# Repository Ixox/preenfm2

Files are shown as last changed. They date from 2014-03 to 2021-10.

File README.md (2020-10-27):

# preenfm2 firmware

Ixox/preenfm2 is the official repository of the preenfm2 firmware.

You can find here the compiled firmware, its code source and some hardware files for the PCB, MCU board and cases.

To flash the preenfm2 for the first time, [follow these instructions](https://github.com/Ixox/preenfm2/tree/master/flash)

## Compiling the firmware

To compile the firmware, you'll need [arm-gcc version 4.7](https://launchpad.net/gcc-arm-embedded/+milestone/4.7-2014-q2-update)

Add the bin directory to your PATH, and run **'make'**, you'll get the list of the available targets.

```bash
$ make
You must chose a target 
Don't forget to clean between different build targets
   clean : clean build directory
   pfm : build pfm2 firmware
   pfmcv : build pfm2 firmware for Eurorack 
   installdfu : flash last compiled firmware through DFU
   zip : create zip with all inside
```
Since some refactoring, the bootloader does not compile anymore. But it's available in its binary format.

Then put your preenfm2 in [bootloader mode](http://ixox.fr/preenfm2/manual/upgrade-firmware/). Look at DFU part 4.

To flash the firmware on the preenfm2 using the DFU protocol :

```bash
make installdfu
```

Once it's done, unplug the power cable and plug it back.

## New Filters in 2.11

Many effects have been added in the firmware 2.11. They were coded by [Toltekradiation](http://ixox.fr/forum/index.php?topic=69544.0).

His github repo is [here](https://github.com/pvig/preenfm2). You'll find there some description of the different effects.

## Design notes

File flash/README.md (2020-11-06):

You may need to flash the memory of the preenfm if it was not done before.

The following need to be done only once. Once the bootloader is flashed, you may boot into it (hold a key while turning on the preenfm2) and flash the firmwares from it.

More information about the preenfm2 bootloader is accessible [here](http://ixox.fr/forum/index.php?topic=69716.0).

# Flash the STM32F405 on Windows

## WebDfu

Flashing the firmware is now possible from a Chrome browser:  
https://devanlai.github.io/webdfu/dfu-util/

If it works this is probabely the easier way.

Reminder to enter DFU mode :
1. Unplug the preenfm
2. Connect the 2 pins of the Boot0 pins of your preenfm2
3. Plug the preenfm

When your preenfm2 is in DFU mode and plugged to your compuer throught USB.

* Click Connect button : select "STM32 Bootloader"
* Then select the first interface of the list "DFU: cfg=1, intf=0, alt=0, name="@Internal Flash /0x08000000/04*016Kg,01*064Kg,07*128Kg"
* Keep default values and go to "Firmware Download". Click "Choose file" and select your "p2_boot_1.13.bin" from your computer.
* Verify your screen with the attached screenshot.
* Click Download

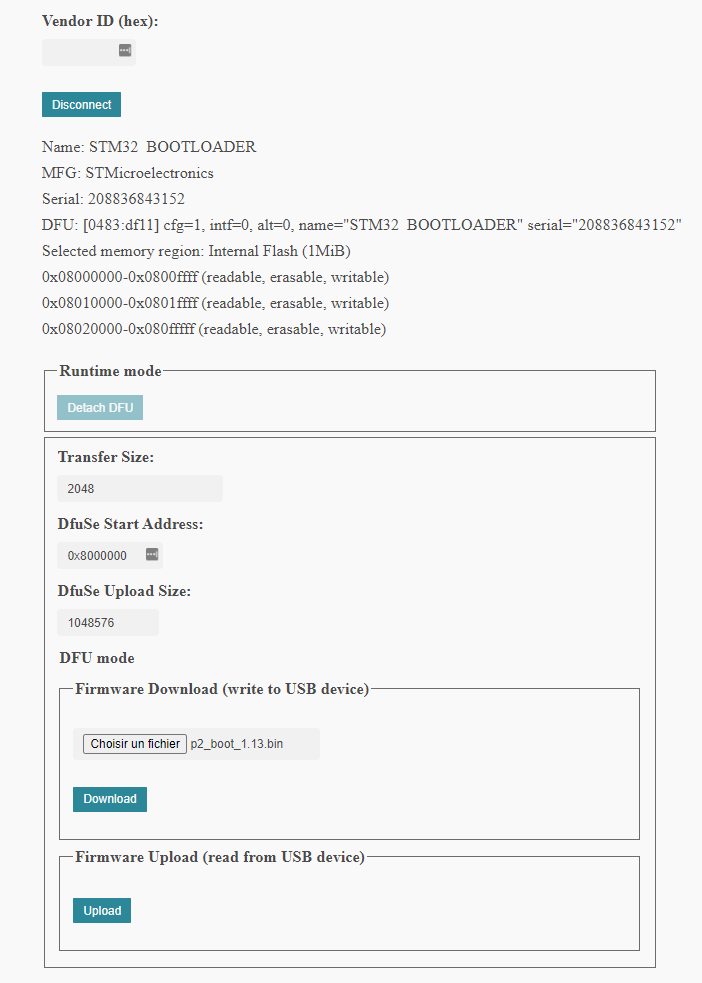
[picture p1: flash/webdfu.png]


Once finished reboot while holding down a key.
You should see "- Bootloader 1.13 -" at the top of the preenfm2 screen.

## DfuSe

Another way is to download [DfuSe](https://www.st.com/en/development-tools/stsw-stm32080.html) from STMicroelectronics.   
It contains the flash programm and the usb required drivers.

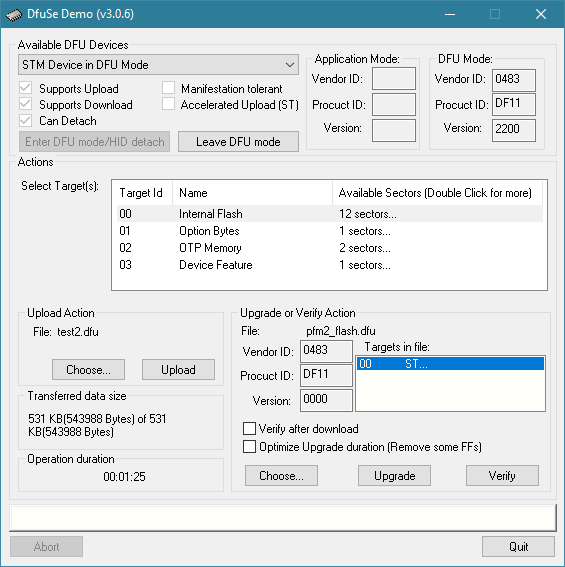
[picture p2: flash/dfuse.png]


Once your preenfm is in DFU mode it should show up in the top left as "STM DEvice in DFU Mode".
Then in the "Upgrade or Verify Action" click on Chose, select the [pfm2_flash.dfu](pfm2_flash.dfu) that should be in the current folder.
And click on Upgrade.

When it's done don't forget to unconnect the 2 pins of Boot0 before turning off and back on your preenfm.

## Windows 3rd solution

Use the commands as explained bellow

# Flash the STM32F405 on MacOs or Linux

On those platforms you'll have to use "dfu-util".

On linux create a new file  /etc/udev/rules.d/46-stm32F405.rules and add this content :
```
   ATTRS{idProduct}=="df11", ATTRS{idVendor}=="0483", MODE="664", GROUP="plugdev"
```

First follow steps 1,2,3 above to enter bootloader mode.

Then flash the bootloader at the adress 0×8000000. (run install_bootloader.cmd from the firmware zip file or from the current folder)

```
dfu-util -a0 -d 0×0483:0xdf11 -D p2_boot_1.11.bin -R -s 0×8000000
```

Flash the firmware at the adress 0×8040000.  (run install_firmware.cmd from the firmware zip file)

```
dfu-util -a0 -d 0×0483:0xdf11 -D pfm2_211.bin -R -s 0×8040000
```

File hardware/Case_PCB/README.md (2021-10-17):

# preenfm2 2021 case

I designed this new case to have a cheap good looking case for the preenfm2.  

The top surface is a PCB. The rest of the case is made by 2 3D printable pieces (main and rear surface).  
The hole for the display fits regular 20x4 **LCD** display such as [this one](https://www.buydisplay.com/arduino-code-lcd-20x4-i2c-character-display-module-wide-view-angle).  
So check the size. You can also modify the provided Kicad PCB file. 

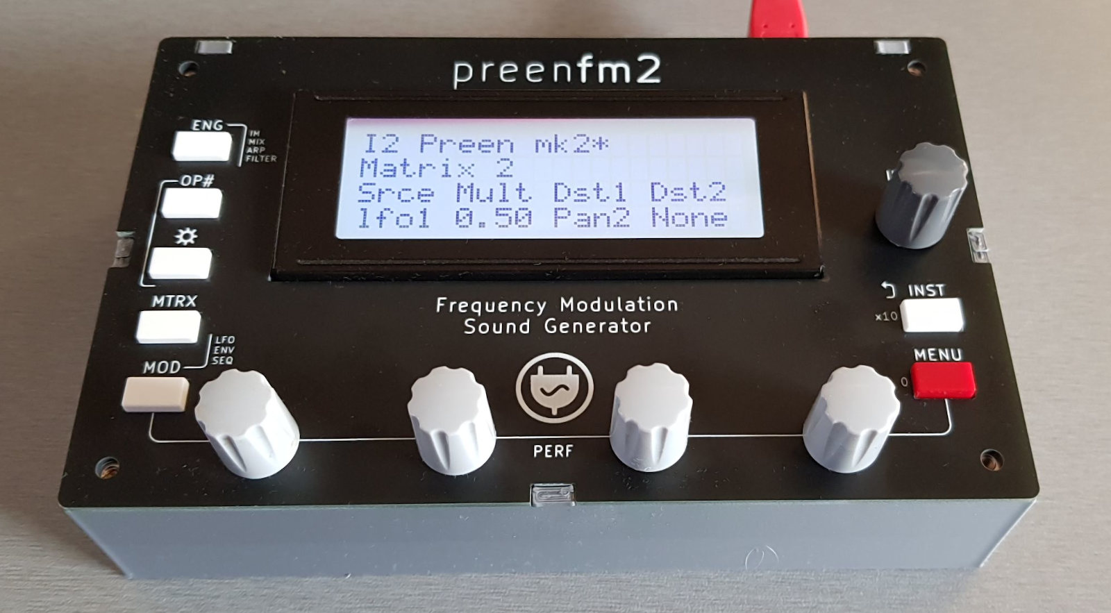
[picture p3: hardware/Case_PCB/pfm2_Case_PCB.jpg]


Other items: 
* 4 * 12 mm F/F spacers
* 2 * 20 mm M/F spacers
* 2 * 15 mm M/F spacers
* 8 * 8 mm screws
* 4 * self adhesive rubber feet (optional)

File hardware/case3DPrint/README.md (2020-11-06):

# 3D Printed Case

Here are 4 stl files that can be printed to make a minimal enclosure for your preenfm2.  
It will work with LCD display, OLED displays are smaller and the result won't be nice.  

The f3d file can be imported into fusion 360. Fusion 360 has a free version for personnal use. Using it you can customize the case and recreate the STM files.

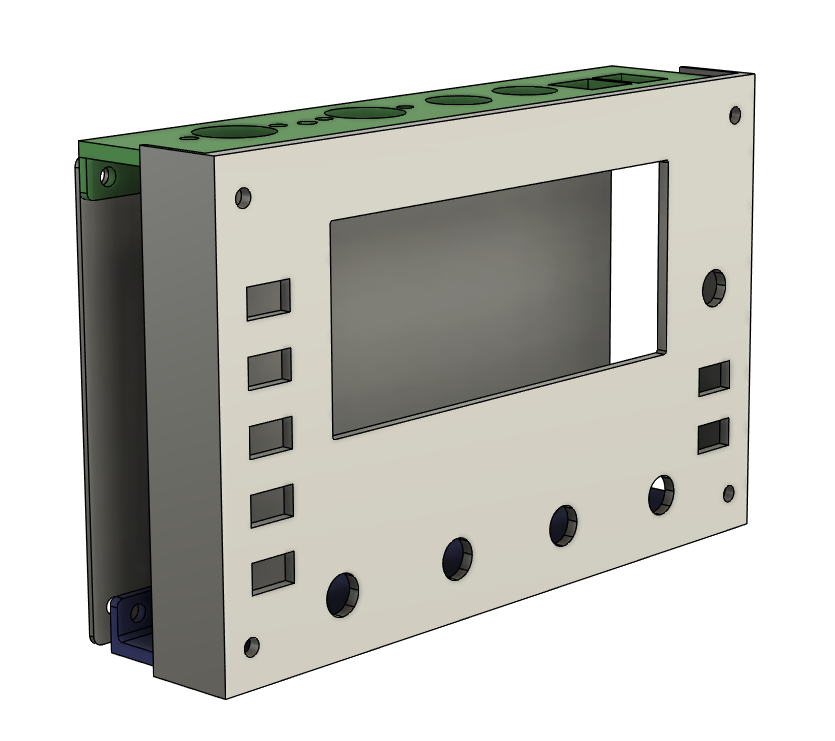
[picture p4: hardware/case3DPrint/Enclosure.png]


Additional hardware :
* 4 * 12 mm F/F spacers
* 2 * 20 mm M/F spacers
* 2 * 15 mm M/F spacers
* 8 * 8 mm screws
* 4 * self adhesive rubber feet (optional)  

Screws and spacers size can be M2.5 or M3.

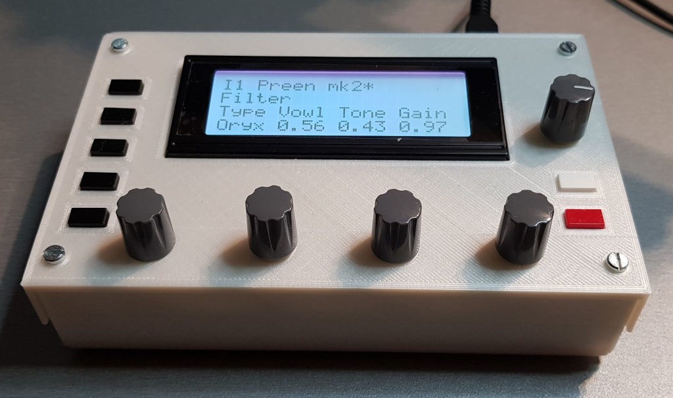
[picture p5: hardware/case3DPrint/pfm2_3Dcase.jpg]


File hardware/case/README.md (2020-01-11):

# Preenfm2 case files

Here are 2 svg files that can be used to have a case made at Formular/Ponoko or any laser cuting company.

Chose the correct file : OLED and LCD 20x4 display don't have the same bezel size.

* To fix the display to the PCB :
    * 2 \* M2.5 screws 16mm
    * 2 \* M2.5 nuts
    * 2 \* Spacer 8mm M3 (ref mouser 855-R30-6700894)
* To fix the 2 midi jacks to the case
    * 4 \* M2.5 screws 8mm
    * 4 \* M2.5 nuts
* To screw the case parts together
    * 9 \* M3 screws 6mm (5 bottom + 4 top)
    * 5 \* DI20 spacers (ref mouser 855-R30-1002002)
    * 4 \* DA11 spacers (ref mouser 855-R30-3001102)
    * 4 \* M3 nuts
    * 4 \* M3 screws 12mm
* Under the case
    * 2 \* stick on feet (ref mouser 517-SJ-5306CL)

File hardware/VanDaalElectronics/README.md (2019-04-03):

# Eurorack PCB eagle files for the preenfm2

Here is the first revision Eagle files for the Eurorack daughter board.
This board converts Modulation inputs (cv3 and CV4) -5V to +5V for Preen AIN
It handles V/Oct 0-8V from CV2 to AIN and Gate from CV1 to AIN.

All the unnamed diodes are general purpose diodes.
Shotky diodes are also what ever fits. As long it has very low forward voltage.

CV inputs can be wired straight to 3.5mm jacks.
Same with MIDI and USB.

+5V needs to be routed to the mainboard.

[Van Daal Electronics DIY Kit](https://vandaal-electronics.com/product/preenfm-eurorack-retrofit-diy-kit/)

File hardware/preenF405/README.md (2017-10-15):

'''html
### PreenF405

Here is the schematic and board of the preenFM microcontroller board.
Files have been created with eagle 6.5.

The BOM used for the official preenF405 is :
<pre>
Manufacturer       Part Number         Designator        Qty  Desciption                       Case            Top/bot Points
Yageo              CC0603KRX7R9BB104   C1, C2, C3, C4    4    100nF,50V,10%,X7R,0603           0603     SMD    Top     2    
Murata             GRM1885C1H200FA01D  C6, C7            2    20pF,50V,1%,C0G,0603             0603     SMD    Top     2    
TDK Corporation    C2012X7R1H225K125AC C8, C9            2    2.2uF,50V,10%,X7R,0805           0805     SMD    Top     2    
Kemet              T491B106K016AT      C10               1    10uF,16V,10%,1411(B)             1411(B)  SMD    Top     2    
Yageo              RC0603FR-0710KL     R1, R2, R3, R6    4    10K,1%,1/10W,0603                0603     SMD    Top     2    
Yageo              RC0603FR-0722RL     R4, R5            2    22R,1%,1/10W,0603                0603     SMD    Top     2    
TXC Corporation    AT-12.000MAGK-T     QA                1    12MHz,20pF,HC49/US               HC49/US  SMD    Top     2    
STMicroelectronics STM32F405RGT6       IC1               1    STM32F405RGT6,64-LQFP            64-LQFP  SMD    Top     64   
TAD                1-2001FBV0T                           2    1*20 Pins,Pitches 2.54mm,180°                    Bot     20   
</pre>

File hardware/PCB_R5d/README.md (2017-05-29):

# Preenfm2 PCB files

Here is the preenfm2 PCB files : revision r5d.<br />
Made with [Kicad](http://kicad-pcb.org/) 3.<br />

<br />
### What's new ?<br />
Compared to r5c, there is an additional resistor that makes [the yellow oled mod](http://ixox.fr/forum/index.php?topic=69159.0) much easier.<br />

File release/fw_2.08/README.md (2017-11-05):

### Do not right click !
Click on the firmware's file, then press Download on the following page.

# What's new in 2.08 ?

# Carrier vs Modulator
#### Direct editing : 
There's a new combo button+encoder: <br />
Modifying some value while pressing the left middle button (button 3 from this picture) will modify  other values at the same time.<br />
If you modify any of the 8 enveloppe parameters while pressing this button, it will modify the other enveloppes of the same operator type in the current algo : all carriers or all modulators. <br />
Exemple with <a href="http://ixox.fr/preenfm2/algorithms/algo15/#main">ALGO 15</a> <br /> 
If you press button 3 while modifying enveloppe of operator 1 (or 3) it will modify 1 & 3 at the  same time.<br />
If you press button 3 while modifying enveloppe of operator 2 (or 4 or 5 or 6) it will modify 2,4,5 & 6 at the same time.<br />
An other example :  Modifying attk of op1 (which is always a carrier operator) while pressing 3 will always modify the attk of the sound because all carriers attk will be modified :)<br />
It also does the following multi-edit :<br />
IM : modifying any modulation index (or v) will edit all IM (or all v) at the same time.<br />
Mix : modifying any mix will change all mix.<br />
Pan : modifying any pan will change all pans.<br />

#### Matric modulation :
The legacy att*, dec*, rel* matrix targets are now envC, decC, relC and modify attack, decay and release of all carrier operator envelopes.<br />
After each one you'll find envM, decM, relM that modify attack, decay and release of all modulator operator envelopes.<br />
Controlling all modulator envelopes with the modwheel (matric source ModW) is very intersting.<br />

#### Midi control:
. Legacy midi CC 80 now modifies enveloppe attacks of all carrier operators.<br />
. Legacy midi CC 81 now modifies enveloppe releases  of all carrier operators.<br />
. New midi CC 62 modifies enveloppe attacks of all modulator operators.<br />
. New midi CC 63 modifies enveloppe releases  of all modulator operators.<br />
Midi page updated : http://ixox.fr/preenfm2/manual/midi/<br />

# LFO Frequency
LFO1-3 frequency can now go up to 99.9Hz.<br />
!!! Your frequencies synced to midi clock (MC/16,  MC/8, MC/4 etc....) will be 24.x Hz after this modification.
Which means you'll have to turn their values up after 99.9 to set back your Midi clock synced values !!!!<br />

# Lokki's modification 
http://ixox.fr/forum/index.php?topic=69326.0<br />
1. hertz mode: in the Operator Oscillator page, chose Ftyp = kehz. That will make "fine tune" (FTun) value behaves in hertz. So that beating stays the same over the whole range of the midi notes.<br />
2. global midi channel: if enabled in the menu (MENU>Tools>Set>Global Ch),  midi coming in to this channel will be sent to all four instruments. <br />

# Step Sequencer and NRPN
NRPN used to always modify the step sequencer of the curren instrument, not the one of the specified midi channel. It's now fixed.

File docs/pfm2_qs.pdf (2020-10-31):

## http://www.preenfm.net

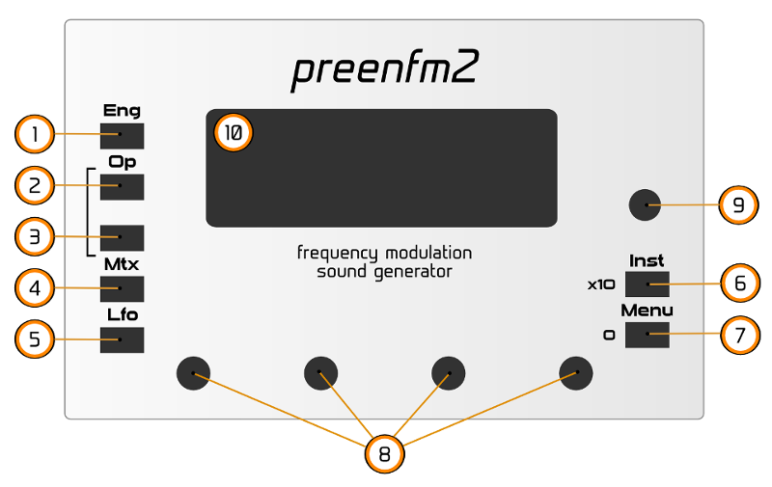
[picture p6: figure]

- Hold 1 + 7 : show current FM algo
- Hold 1 + 6 : show current IM
- Mix, pan, env edit : hold 3 to modify all other carrier/modulator operators at the same time
- Hold 1, 2, 4, 5, 6 and turn any encoder to navigate quickly through the pages
- Hold any key while powering the preenfm enter bootloader to flash new firmware.
- Hold 6 + encoder : modify value 10 times faster
- Hold 7 + encoder : reset value
- Hold 1 and press 2 : go to main engine page.
- Hold 6 + 1-5 : play note

1 – 5 : preset edition. Press same button again or (button + encoder) to navigate through the pages of each button.
6 : change curent instrument or ‘back’ in menu mode
7 : enter menu mode (in menu mode 6 become back button) 8 : change values
9 : analog volume

1 : engine, Modulation, Mixer, Arpegiator, Filter
2 : operator from 1 to 6
3 : for operator selected in 2 : waveform, enveloppe
4 : matrix row from 1 to 12
5 : LFO and modulators : lfo1-3, env1-2, step seq 1-2, midi note modulator 5 + 7 (or 8 if clickable) : performance

You enter menu after pressing 7
6 is the Back button. When at the top, returns to edit mode. . Load > Bank, Combo, DX7, Randomiser
. Save > Bank, Combo, Default combo
. Tools > settings, create, rename, Scala
Randomizer : encoder to modify what is changed, 1-5 button to trigger new random Settings: Enc 1 changes setting, Enc 2 changes value. Press 7 again to save.

## Edit Menu Tips

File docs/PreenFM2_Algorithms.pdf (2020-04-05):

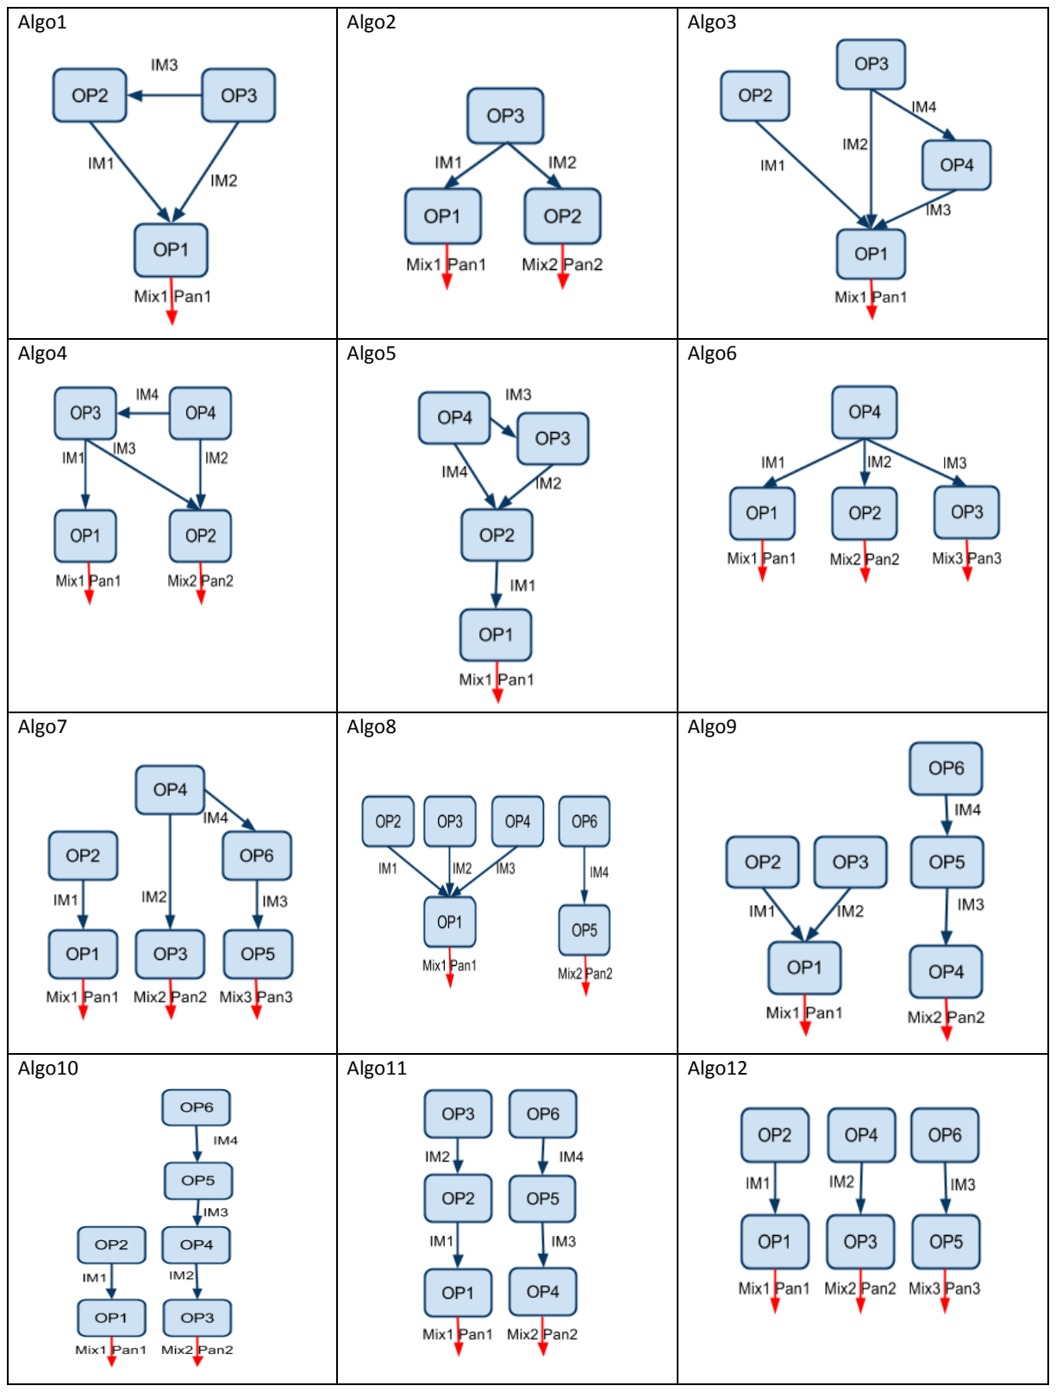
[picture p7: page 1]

Algo1 | Algo2 | Algo3
Algo4 | Algo5 | Algo6
Algo7 | Algo8 | Algo9
Algo10 | Algo11 | Algo12

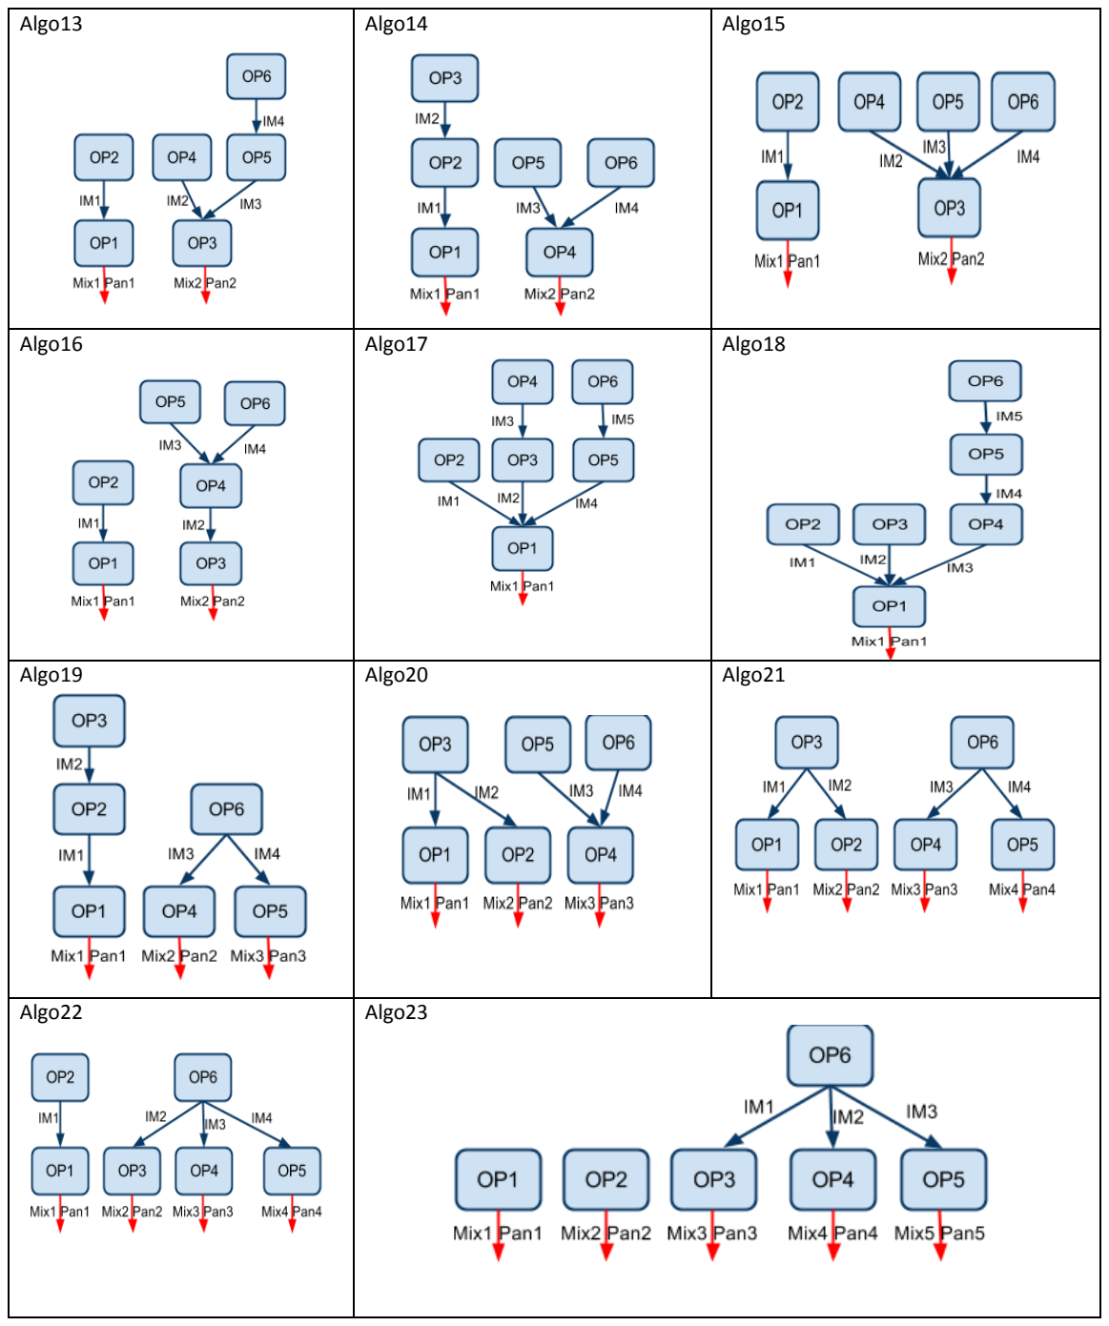
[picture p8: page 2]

Algo13 | Algo14 | Algo15
Algo16 | Algo17 | Algo18
Algo19 | Algo20 | Algo21
Algo22 | Algo23

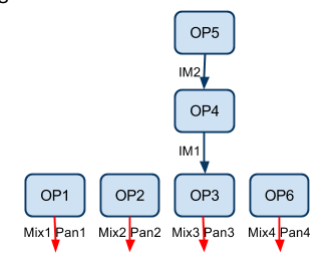
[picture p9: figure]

Algo24 | Algo25 | Algo26

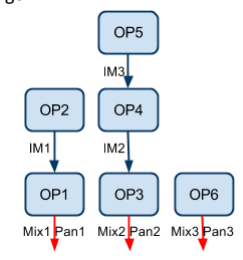
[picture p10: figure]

Algo27

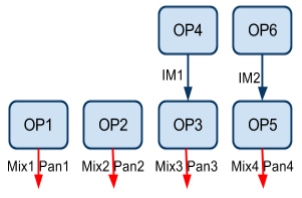
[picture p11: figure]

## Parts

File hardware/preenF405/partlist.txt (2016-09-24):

Partlist

Exported from Preen40.brd at 16/02/14 18:25

EAGLE Version 6.5.0 Copyright (c) 1988-2013 CadSoft

Assembly variant: 

Part     Value          Package  Library  Position (inch)       Orientation

C1       .1uF           C0603K   rcl      (1.144 0.138)         R0
C2       .1uF           C0603K   rcl      (0.6725748 0.581)     R180
C3       .1uF           C0603K   rcl      (0.666 0.1434252)     R180
C4       .1uF           C0603K   rcl      (1.1394252 0.577)     R180
C6       20pF           C0603K   rcl      (1.357 0.3555748)     R0
C7       20pF           C0603K   rcl      (1.66562992 0.35768504) R0
C8       2.2uF          C0805K   rcl      (0.50314961 0.5384252) R90
C9       2.2uF          C0805K   rcl      (0.5075748 0.225)     R180
C10      10uF           CT3528   rcl      (0.152 0.198)         R0
IC1      STM32F40X      LQFP64   GHI      (0.90622835 0.35779134) R90
JP1                     1X01     pinhead  (0.06 0.06)           R0
JP2                     1X01     pinhead  (0.16 0.06)           R90
JP3                     1X01     pinhead  (0.26 0.06)           R90
JP4                     1X01     pinhead  (0.36 0.06)           R90
JP5                     1X01     pinhead  (0.46 0.06)           R90
JP6                     1X01     pinhead  (0.56 0.06)           R90
JP7                     1X01     pinhead  (0.66 0.06)           R90
JP8                     1X01     pinhead  (0.76 0.06)           R90
JP9                     1X01     pinhead  (0.86 0.06)           R90
JP10                    1X01     pinhead  (0.96 0.06)           R90
JP11                    1X01     pinhead  (1.06 0.06)           R90
JP12                    1X01     pinhead  (1.16 0.06)           R90
JP13                    1X01     pinhead  (1.26 0.06)           R90
JP14                    1X01     pinhead  (1.36 0.06)           R90
JP15                    1X01     pinhead  (1.46 0.06)           R90
JP16                    1X01     pinhead  (1.56 0.06)           R90
JP17                    1X01     pinhead  (1.66 0.06)           R90
JP18                    1X01     pinhead  (1.76 0.06)           R90
JP19                    1X01     pinhead  (1.86 0.06)           R90
JP20                    1X01     pinhead  (1.96 0.06)           R90
JP21                    1X01     pinhead  (1.96 0.66)           R0
JP22                    1X01     pinhead  (1.86 0.66)           R0
JP23                    1X01     pinhead  (1.76 0.66)           R0
JP24                    1X01     pinhead  (1.66 0.66)           R0
JP25                    1X01     pinhead  (1.56 0.66)           R0
JP26                    1X01     pinhead  (1.46 0.66)           R0
JP27                    1X01     pinhead  (1.36 0.66)           R0
JP28                    1X01     pinhead  (1.26 0.66)           R0
JP29                    1X01     pinhead  (1.16 0.66)           R0
JP30                    1X01     pinhead  (1.06 0.66)           R0
JP31                    1X01     pinhead  (0.96 0.66)           R0
JP32                    1X01     pinhead  (0.86 0.66)           R0
JP33                    1X01     pinhead  (0.76 0.66)           R0
JP34                    1X01     pinhead  (0.66 0.66)           R0
JP35                    1X01     pinhead  (0.56 0.66)           R0
JP36                    1X01     pinhead  (0.46 0.66)           R0
JP37                    1X01     pinhead  (0.36 0.66)           R0
JP38                    1X01     pinhead  (0.26 0.66)           R0
JP39                    1X01     pinhead  (0.16 0.66)           R0
JP40                    1X01     pinhead  (0.06 0.66)           R0
Q1       12Mhz          SM49@1   crystal  (1.49967717 0.23574803) R180
R1       10K            R0603    rcl      (0.42029921 0.537)    R90
R2       10K            R0603    rcl      (1.9639685 0.17359843) R90
R3       10K            R0603    rcl      (0.4975748 0.339)     R180
R4       22             R0603    rcl      (0.245 0.428)         R270
R5       22             R0603    rcl      (0.154 0.429)         R270
R6       10K            R0603    rcl      (1.49 0.359)          R180

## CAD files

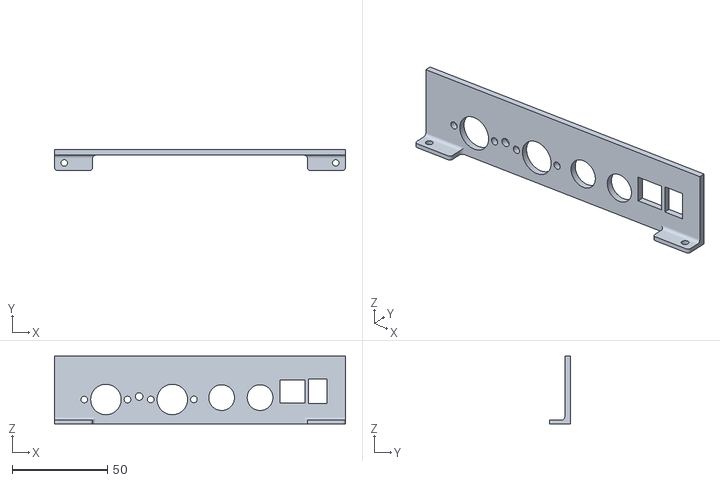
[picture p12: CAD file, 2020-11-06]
hardware/case3DPrint/rear.stl
152.6 x 11.0 x 35.4

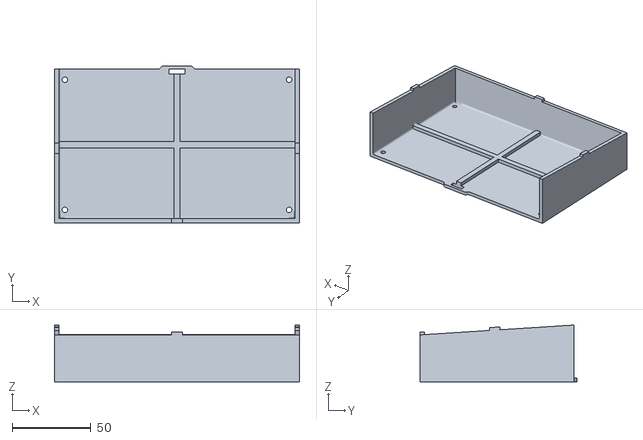
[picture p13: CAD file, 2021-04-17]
hardware/Case_PCB/pfm2-Case.stl
155.4 x 99.8 x 36.1

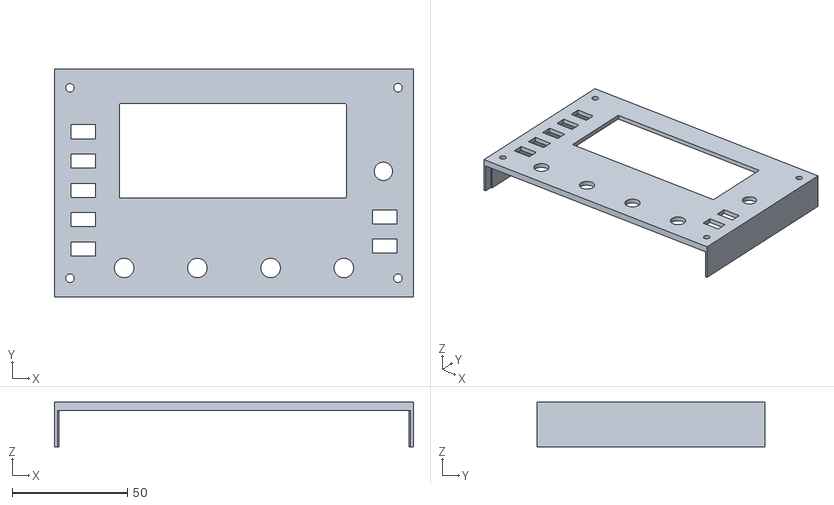
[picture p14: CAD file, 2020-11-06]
hardware/case3DPrint/top.stl
155.8 x 99.1 x 19.4

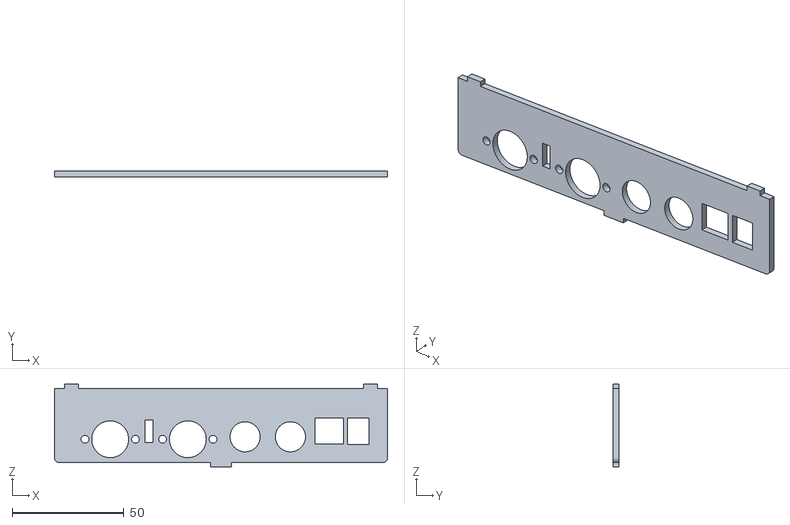
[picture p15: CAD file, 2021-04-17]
hardware/Case_PCB/pfm2-Rear.stl
149.2 x 2.70 x 37.1

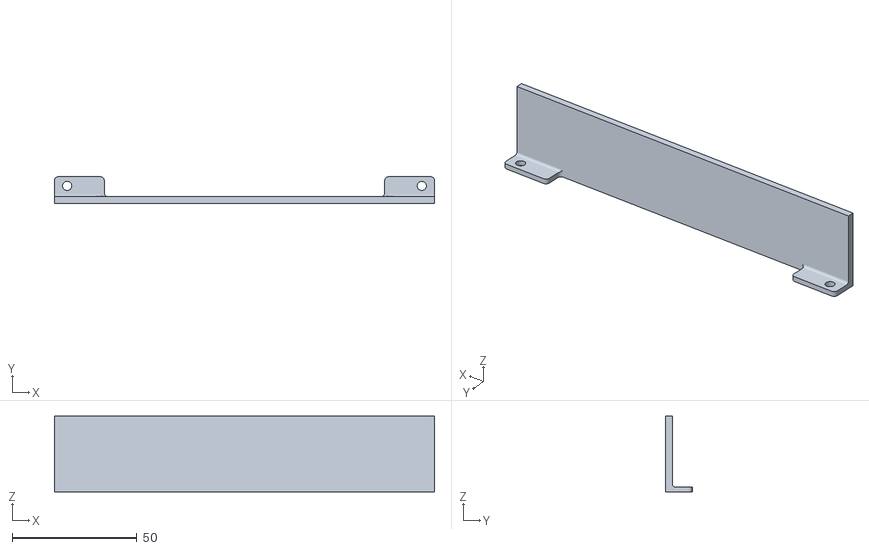
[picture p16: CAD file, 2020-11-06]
hardware/case3DPrint/front15mm.stl
152.6 x 10.7 x 30.4

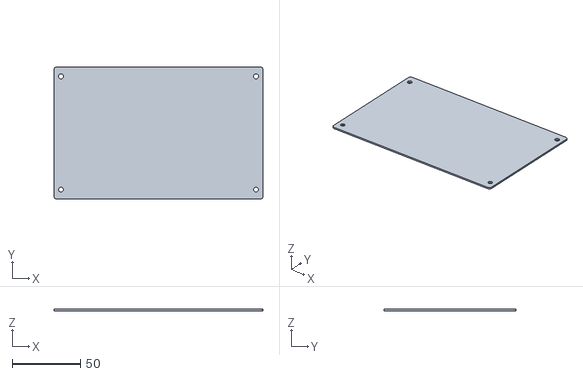
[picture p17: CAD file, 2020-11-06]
hardware/case3DPrint/bottom.stl
152.6 x 96.7 x 1.20

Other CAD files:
hardware/case3DPrint/pfm2case.f3d

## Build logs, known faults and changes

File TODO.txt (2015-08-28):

2.00b1
. Rel* at Att* are back and Per voice :)
. polyphony fixed in instruments 2,3,4
. LFO phase now works when LFO freq is midi synced
. Optimization when LFOs or MAtrix rows are not used.
. Decreased number of voices max when to 14.
. Midi NRPN ready for editor
. Bit crusher optimization (it took a lot of CPU). 

TODO (temporary list, grow over time) : 

OK to test  
. Freeze when no file on USB
. env attack as target...

DONE:
. Fixed ENV1 release, that did not release when > 1.0
. Renamed "LFO Env" => "Free Env", "LFO step" => "Step Seq"
. KSyn : change to 16s max
. Algo28 : IM2 shows up !
. Patch and bank change by midi
. Midi through latency : move into interupt
. Fine tune too hard !
. LFO frequency finer
. DX7 bank that start with $
. Bug: can increase number of voice after having loaded a new preset.
. Modify button : Osc->Operator# , Env : Osc, EnvA, EnvB ?
. 'Panic!' to add... Voice = 0 enough ?
. Play note in combo (spec)
. But when release > 8 secs
. USB Midi : SYSEX, after touch, program change..
. Bootloader can now jump to STM32 ROM dfu loader
. New midi/USB cable tested...
. audio glich when changing patch while playing and start again plaing (seems to be linked with voice). Reset env*Mem in voice killNow().
. ADD All DX7 algos for compatibility + Hexter coversion 
. Fix NRPN and CC... with new scale...
. Sort Combo, banks and DX7Banks alphabeticaly.
. Rename bank...
. Add bankname in Bank SYSEX...
. SYSEX : use new bank selection.. Ask for name ?
. But when push + turn back : row engine 1 : mix5... shows up.
. Use empty PFM patch before applying DX7 parameters.
. Use back+turn to fine adjust (Remove the Modulation special case)
. use menu+turn to reset to default
. '_' for read only bank).
. Chose combo and preset bank by name
. Release LFO ENV1 Broken - LCD - show up at 1.00
. '*' appear on the last letter of the preset name...
. Bug env release when release level > 0
. Enveloppe expenential
. BUG when one of the OSC is OFF
. env all release as target.
. Add mix4/pan4 to matrix. No 5 and 6.
. Clean old CC from matrix...
. Rename LFO on LCD
. Pitch bend 1 modwheel to adjust (too strong).
. DX7 sysex can be read directly from USBKey thought the menu (300 banks * 32 patch max)
. Turn encoder while button pressed : browse row
. Bug : voice = 0 after patch load
. SYSEX USART
. USB CC + real time evant.
. USB midi : buggy with Ipad.
. algo 7 & 8 missing
. Chose patch when saving always load first bank
. Tools>Set>Name : start on second car instead of 1st.
. Preset modified per timbre
. Gliding fixed
. Bug note off when voice=1
. Bug when voice = 0... freeze
. MIDI CC
. MIDI nrpn
. No more click during lcd.clear()
. LFO Osc midi clock OK
. Combo name KO... saved "com 0" and after reboot see : "com 0##G"...
. Can reset default combo
. Default saved as patched instead of combo
. Custom bootloader : flash new firmware from USBKey
. Different options when booting
. remove single mode from code (midi config)
. Check new param value in SynthState.encoderTurned() (Voices and Algo)...
. Combo name
. turns usbKey_usr.c into a class
. several banks
. save midi config on USB Key
. lfo env 2 : silence as target
. 9V wall adapter does not work : fixed in R4d
. Cannot upload firmware with USB : dfu-util >= 0.6 : 
	dfu-util -a0 -d 0x0483:0xdf11 -D $(BIN_BOOTLOADER) -R -s 0x8000000
. Rename patch (modify menu)

What's new PreenFM2 : 
. multi timbral : 4 timbres 
. more voices, flexible allocation : 48 operators to spread in the the 4 timbres...
. stereo : pan of carrier operators modifiable + targetable in the matrix
. Midi through USB (DIN5 still available)
. patches and banks storage on USB Key. 
. DX7 dump sysex file readable from USB Key (don't expect miracle but a great source of new sounds).
. New LFO env (silence, attack, decay, loop) Silence time targetable in the matrix to make it change (saw that in the Mopho).
. Enveloppe attack, decay, release in seconds.. comprehensive tweaking.
. DAC 18 bits : 12 + 6 bits... 
. sampling rate 38khz
. Full floating point engine (32 bits)
. Pins available for any future evolution (analog input, surface control expansion, mutable instrument SMR4 mkII...)
. DC 2.1mm for 7.5V or 9V wall adapter
. Custom bootloader : flash new firmware from USBKey

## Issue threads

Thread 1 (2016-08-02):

make the project open-complete

axd1967, 2016-08-02:
looks like a very nice project (found it via http://audiocookbook.org/the-most-powerful-tiny-fm-synth-preenfm2/).

however, there is an issue. this repo contains the sourcecode, but what is missing is

* user manual (now separate at http://ixox.fr/preenfm2/manual/, but in fact intimately linked to the firmware!!! imagine you add a feature to the firmware... you would also have to add changes to the manual! and in an ideal world, all those changes are done on a branch...)
* PCB (manual, diagrams, ..., now at https://docs.google.com/spreadsheets/d/1Xt8gQqbJvMSSZ3lOPazCrE3Qu6qT4qbJweNDEm-yr78/edit#gid=0, and http://ixox.fr/preenfm2/build-it/thebuild/, rather linked to the firmware, no? just imagine you replace a encoder knob with more capabilities - it is likely the software would have to be updated too!)
* build manual (now at http://ixox.fr/preenfm2/build-it/, not so linked with the sourcecode, but linked to the PCB, right? and think of the knob that changed... this must also be mentioned in the build manual, right?)

and maybe also
* alternative banks (http://ixox.fr/preenfm2/download/)
* case design files
* links to interesting sites, such as https://www.youtube.com/watch?v=ZzsBu9vx98Q (which you should put in a playlist, so you can collect all related videos and link to it!)

and maybe also the compiled artefacts (that are now on http://ixox.fr/preenfm2/download/)! this is undoubtedly open for discussion, as derived artefacts don't really belong in a repo for various reasons; but while you're at concentrating everything, and because the binaries are not that big, why not version them too? then you don't need to update the preenFM2 site or use Dropbox (gah!) any more. (and BTW - there is only one firmware binary, called `pfm2` or even `pfm`, no need to add version numbers!).

and it doesn't matter that soft- and hardware might be designed by several people, the end result is one object that has a history, revisions, of various artefacts that evolve together! those different people should clone the repo and contribute as necessary.

also, by versioning everything, anyone trying to track updates only needs to perform a pull, and presto! (s)he can immediately see everything that has changed since whenever (s)he last made a pull, without having to search on http://ixox.fr/preenfm2/ to find out what changed (and probably miss things): manuals, firmware, ...

now imagine you want to make version 3... new PCB, new firmware, maybe a slightly different case.... you likely won't start from scratch, but tweak a version 2 system (maybe a lot, yet...), right? maybe versions will share code? imagine that someone finds a bug in a model 3, and that bug also appears in model 2, and the correction is almost the same in all models? you will have to juggle with branches, but all information is centralised in **one repo**. if those were in different repos, owners of different models might not be aware of issues that might be common to all models...
just by looking at your model PreenFM1, I can see version 2 is an evolution (even if much changed), so it belongs in the same project! and a new project would start off as a branch... because your version 2 might continue to evolve long after you've given up on it, think of the owners of a v2 that still want to contribute with forked code... imagine they find things that could also apply to newer versions...

axd1967, 2016-11-18:
the commits tell me that this issue will slowly get resolved :-)

Ixox, 2017-05-29:
Slowly gets resolved... today i added the PCB latest revision.
And yes i agree with all what you wrote ;)

axd1967, 2021-05-25:
Another feature that further increases long-term survival of this project is the GitHub Archive Program: https://archiveprogram.github.com/faq/

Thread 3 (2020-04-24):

LFO to MIX4 or PAN4 not working

p1nh0, 2020-04-24:
The LFO modulation works on every MIX or PAN except for slot number 4.

I'm using version 2.11 but the same happened on version 2.08

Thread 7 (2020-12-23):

USB Key sometimes not working

modlfo, 2020-12-23:
Hi

I just finished building my Preenfm (PCB R6). I didn't know the USB key was required to work, so I just grabbed the first (and only) one I had in my drawer. It seems to work if I connect it after powering on the unit. But if I turn the Preenfm off and plug it back, sometimes the USB key is not detected and I get the message "Insert Usb Key". If I disconnect it and reconnect it, it is detected and the unit runs fine.

I'm powering it from the USB port. My guess is that the powering sequence of the unit is not happening such my USB key is ready or working by the time the Preenfm reads it. I was wondering if you have seen a similar problem.

I'm going to try to find other USB Key and check it.

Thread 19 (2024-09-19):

Preenfm2 case compatibility with preenfm1

ibz, 2024-09-19:
Is the preenfm2 case compatible with preenfm1?

If so, I can probably add a note to the preenfm1 README, just in case somebody is looking for how to build a case for it, with a link to the preenfm2 case.

ibz, 2024-09-19:
I just printed the top and it is not compatible, so never mind. I'll keep searching for a preenfm1 case model...

Closed 2024-09-19.

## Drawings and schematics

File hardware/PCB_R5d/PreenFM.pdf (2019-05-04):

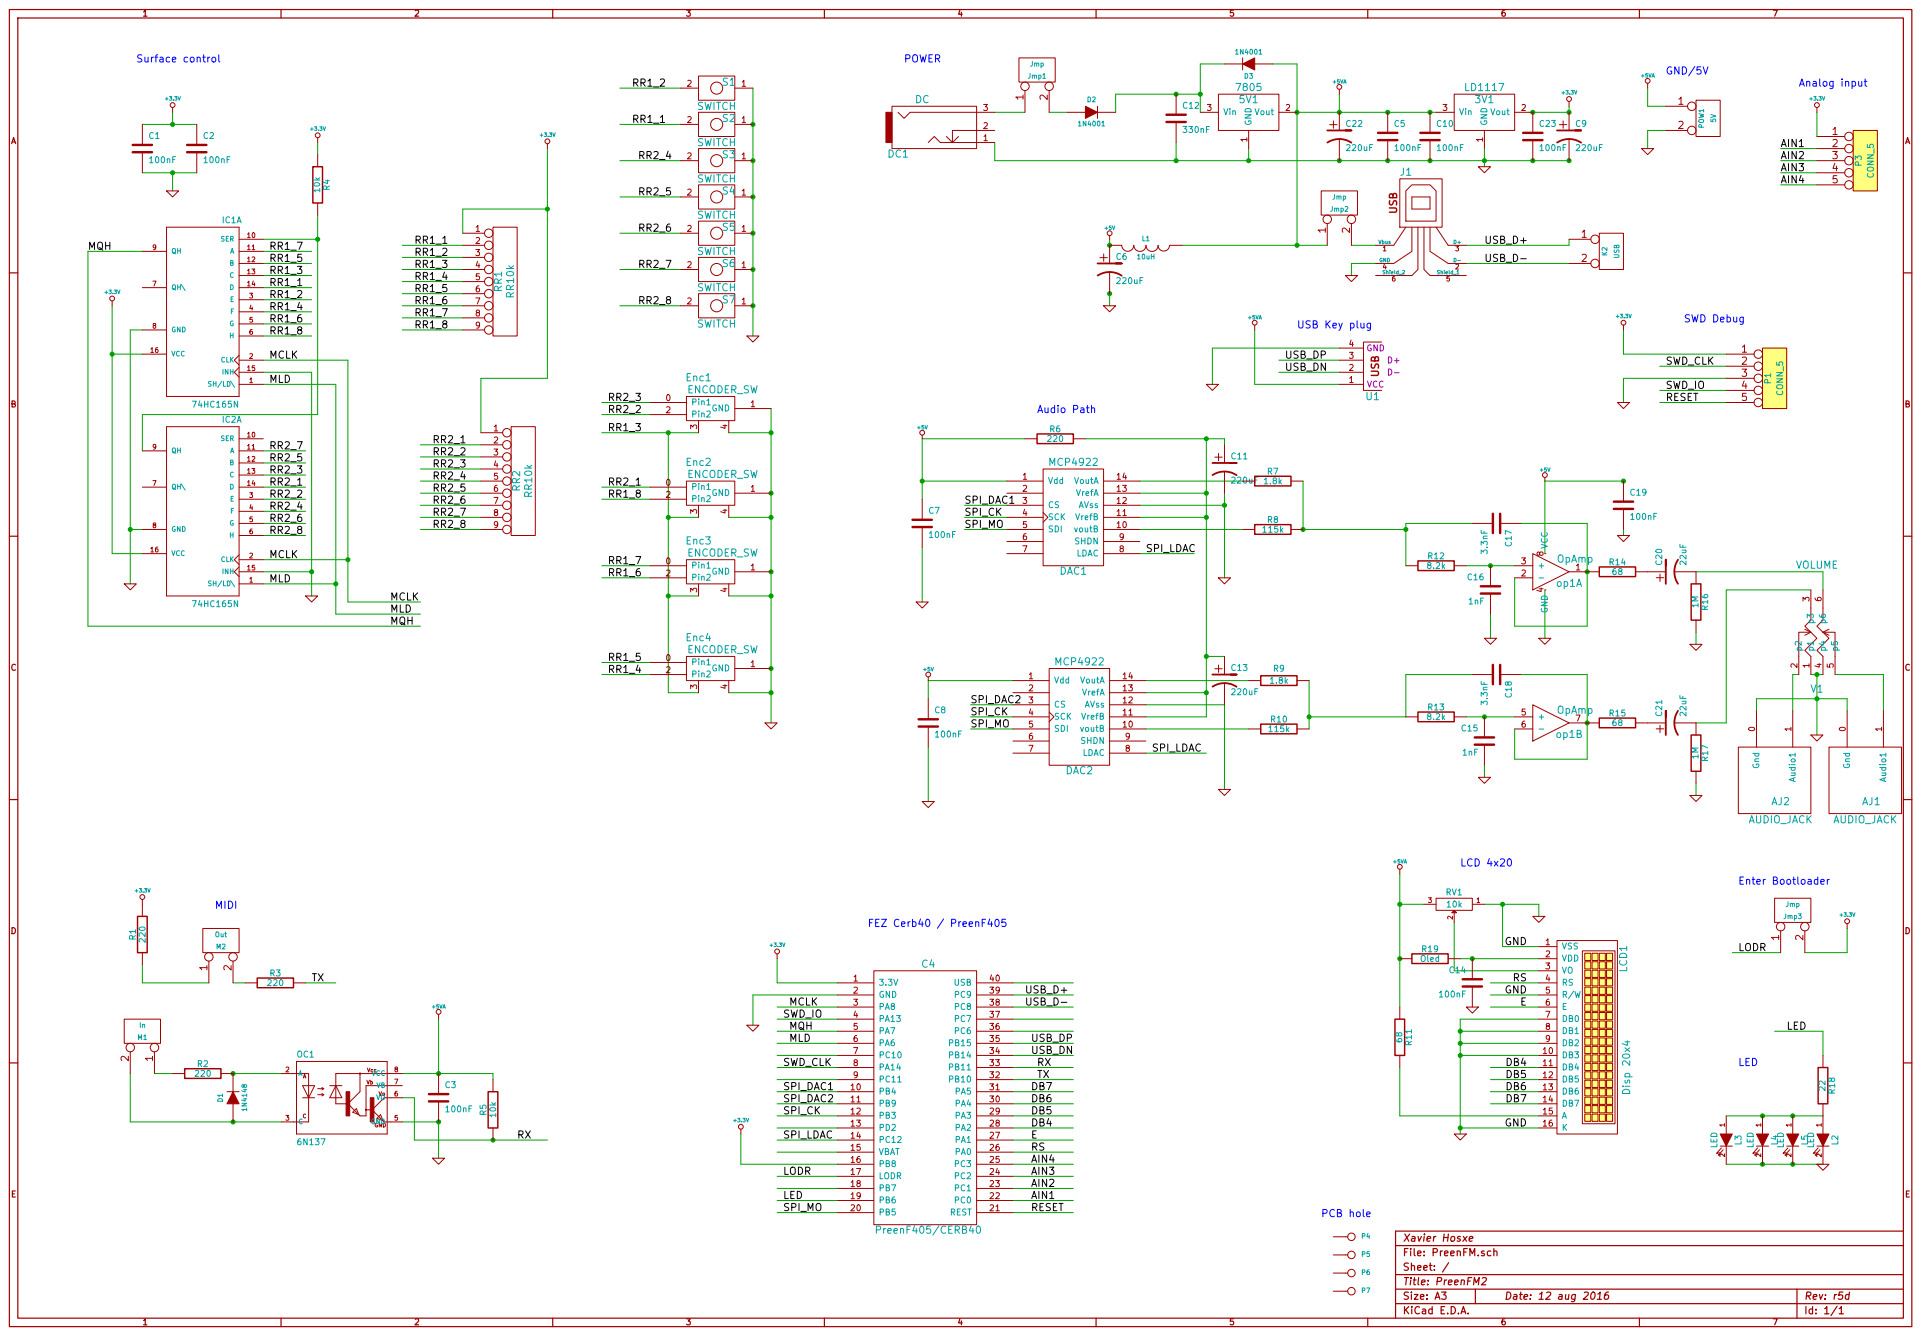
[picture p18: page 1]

D- D+ GND USB Key plug

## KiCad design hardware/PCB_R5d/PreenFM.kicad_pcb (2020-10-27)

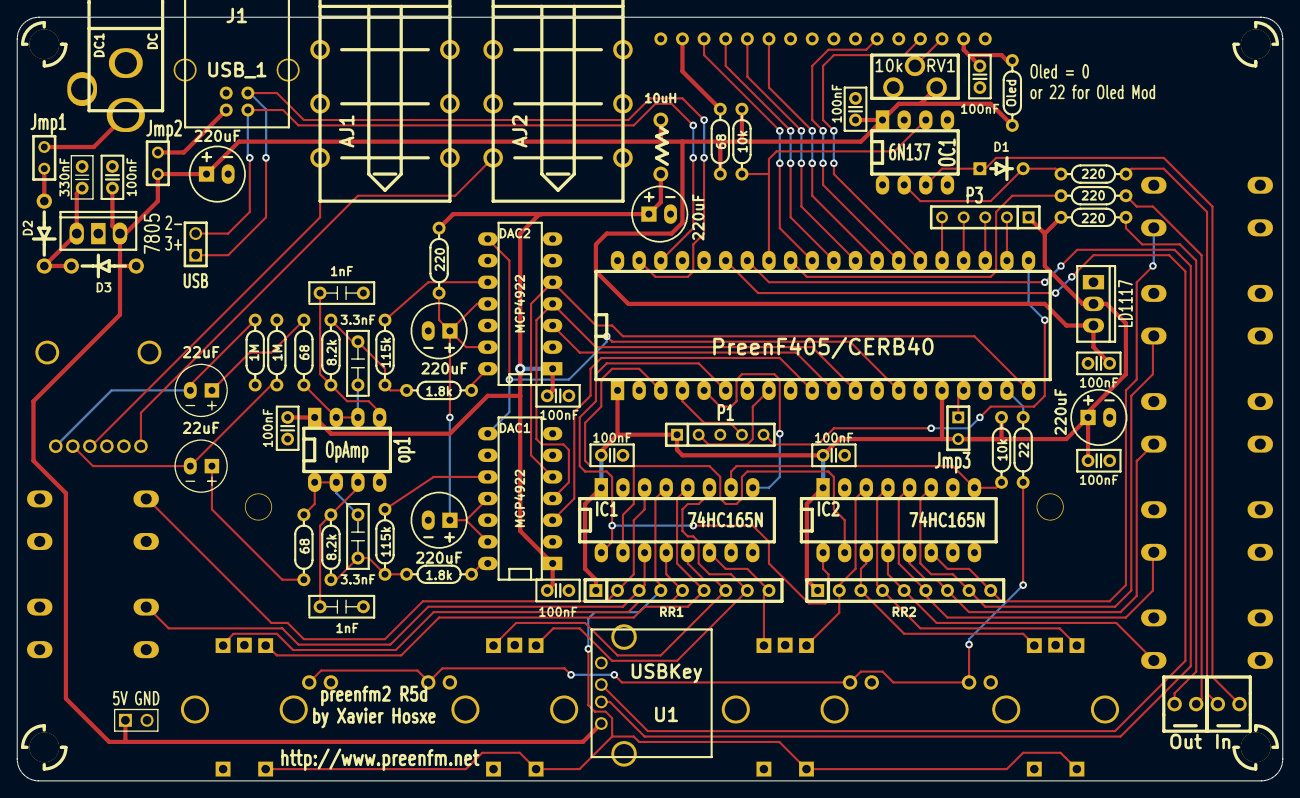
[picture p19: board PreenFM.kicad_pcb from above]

Board: 2 copper layers, 148.6 x 89.7 mm, 92 parts (0 on the bottom side), 80 nets.

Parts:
3V1: LD1117; FMLD1117
5V1: 7805; FM7805
AJ1, AJ2: AUDIO_JACK; FMJACK
C1, C2, C3, C5, C7, C8, C10, C14, C19, C23: 100nF; FMCondeDecouplage2
C4: PreenF405/CERB40; DIP-40__600_ELL
C6, C9, C11, C13, C22: 220uF; FMCondoChimique2
C12: 330nF; FMCondeDecouplage
C15, C16: 1nF; FMCondoPlastic
C17, C18: 3.3nF; FMCondoPlastic
C20, C21: 22uF; FMCondoChimique_10uF_2
D1: 1N4148; FMDiode2
D2, D3: 1N4001; FMDiode1N4001_2
DAC1, DAC2: MCP4922; FM_mcp4922_2
DC1: DC; JACK_ALIM4
Enc1, Enc2, Enc3, Enc4: ENCODER_SW; FMEncoderWithSwitch2
IC1, IC2: 74HC165N; DIP-16__300_ELL
J1: USB_1; FMUSB2
Jmp1, Jmp2, Jmp3: Jmp; SIL-2
K2: USB; SIL-2
L1: 10uH; FMInductance
L2, L3, L4, L5: LED; FMLed
LCD1: Disp_20x4; FMLCD4x20_2
M1: In; FMMidi2
M2: Out; FMMidi2
OC1: 6N137; DIP-8__300_ELL
P1, P3: CONN_5; SIL-5
P4, P5, P6, P7: CONN_1; FMHole3mm
POW1: 5V; PIN_ARRAY_2X1
R1, R2, R3, R6: 220; FMResistance
R4, R5: 10k; FMResistance
R7, R9: 1.8k; FMResistance
R8, R10: 115k; FMResistance
R11, R14, R15: 68; FMResistance
R12, R13: 8.2k; FMResistance
R16, R17: 1M; FMResistance
R18: 22; FMResistance
R19: Oled; FMResistance
RR1, RR2: RR10k; FMRR9
RV1: 10k; FMRV2
S1, S2, S3, S4, S5, S6, S7: SWITCH; FMButton2
U1: USBKey; FMUSB_A
V1: VOLUME; FMDualPotALPS
op1: OpAmp; DIP-8__300_ELL

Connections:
+3.3V: 3V1.2, C1.1, C2.1, C4.1, C4.16, C9.1, C23.1, IC1.16, IC2.16, Jmp3.2, P1.1, P3.1, R1.2, R4.1, RR1.1, RR2.1
+5V: C6.1, C7.1, C8.1, C19.1, DAC1.1, DAC2.1, L1.2, R6.1, op1.8
+5VA: 3V1.3, 5V1.2, C3.1, C5.1, C10.1, C22.1, D3.1, Jmp2.1, L1.1, OC1.8, POW1.1, R5.2, R11.2, R19.2, RV1.3, U1.1
/AIN1: C4.22, P3.2
/AIN2: C4.23, P3.3
/AIN3: C4.24, P3.4
/AIN4: C4.25, P3.5
/DB4: C4.28, LCD1.11
/DB5: C4.29, LCD1.12
/DB6: C4.30, LCD1.13
/DB7: C4.31, LCD1.14
/E: C4.27, LCD1.6
/LED: C4.19, R18.1
/LODR: C4.17, Jmp3.1
/MCLK: C4.3, IC1.2, IC2.2
/MLD: C4.6, IC1.1, IC2.1
/MQH: C4.5, IC1.9
/RESET: C4.21, P1.5
/RR1_1: IC1.14, RR1.2, S2.2
/RR1_2: IC1.3, RR1.3, S1.2
/RR1_3: Enc1.3, Enc2.3, Enc3.3, Enc4.3, IC1.13, RR1.4
/RR1_4: Enc4.2, IC1.4, RR1.5
/RR1_5: Enc4.0, IC1.12, RR1.6
/RR1_6: Enc3.2, IC1.5, RR1.7
/RR1_7: Enc3.0, IC1.11, RR1.8
/RR1_8: Enc2.2, IC1.6, RR1.9
/RR2_1: Enc2.0, IC2.14, RR2.2
/RR2_2: Enc1.2, IC2.3, RR2.3
/RR2_3: Enc1.0, IC2.13, RR2.4
/RR2_4: IC2.4, RR2.5, S3.2
/RR2_5: IC2.12, RR2.6, S4.2
/RR2_6: IC2.5, RR2.7, S5.2
/RR2_7: IC2.11, RR2.8, S6.2
/RR2_8: IC2.6, RR2.9, S7.2
/RS: C4.26, LCD1.4
/RX: C4.33, OC1.6, R5.1
/SPI_CK: C4.12, DAC1.4, DAC2.4
/SPI_DAC1: C4.10, DAC1.3
/SPI_DAC2: C4.11, DAC2.3
/SPI_LDAC: C4.14, DAC1.8, DAC2.8
/SPI_MO: C4.20, DAC1.5, DAC2.5
/SWD_CLK: C4.8, P1.2
/SWD_IO: C4.4, P1.4
/TX: C4.32, R3.2
/USB_D+: C4.39, J1.3, K2.1
/USB_D-: C4.38, J1.2, K2.2
/USB_DN: C4.34, U1.2
/USB_DP: C4.35, U1.3
GND: 3V1.1, 5V1.1, AJ1.0, AJ2.0, C1.2, C2.2, C3.2, C4.2, C5.2, C6.2, C7.2, C8.2, C9.2, C10.2, C11.2, C12.2, C13.2, C14.2, C15.2, C16.2, C19.2, C22.2, C23.2, DAC1.12, DAC2.12, DC1.1, Enc1.1, Enc1.4, Enc2.1, Enc2.4, Enc3.1, Enc3.4, Enc4.1, Enc4.4, IC1.8, IC1.15, IC2.8, IC2.15, J1.4, L2.2, L3.2, L4.2, L5.2, LCD1.1, LCD1.5, LCD1.7, LCD1.8, LCD1.9, LCD1.10, LCD1.16, OC1.5, P1.3, POW1.2, R16.2, R17.2, RV1.1, S1.1, S2.1, S3.1, S4.1, S5.1, S6.1, S7.1, U1.4, V1.1, V1.4, op1.4
unnamed: IC1.10, IC2.9, R4.2
unnamed: AJ1.1, V1.5
unnamed: M2.1, R1.1
unnamed: C17.1, R14.1, op1.1, op1.2
unnamed: C18.1, R15.1, op1.6, op1.7
unnamed: C20.1, R14.2
unnamed: C21.1, R15.2
unnamed: DAC1.14, R7.1
unnamed: C15.1, R13.2, op1.5
unnamed: DAC2.14, R9.1
unnamed: DAC2.10, R10.1
unnamed: DAC1.10, R8.1
unnamed: C17.2, R7.2, R8.2, R12.1
unnamed: AJ2.1, V1.2
unnamed: C20.2, R16.1, V1.6
unnamed: D2.1, Jmp1.2
unnamed: DC1.3, Jmp1.1
unnamed: LCD1.15, R11.1
unnamed: C16.1, R12.2, op1.3
unnamed: J1.1, Jmp2.2
unnamed: LCD1.3, RV1.2
unnamed: M1.1, R2.1
unnamed: M2.2, R3.1
unnamed: D1.2, OC1.2, R2.2
unnamed: D1.1, M1.2, OC1.3
unnamed: C18.2, R9.2, R10.2, R13.1
unnamed: 5V1.3, C12.1, D2.2, D3.2
unnamed: C21.2, R17.1, V1.3
unnamed: C14.1, LCD1.2, R19.1
unnamed: C11.1, C13.1, DAC1.11, DAC1.13, DAC2.11, DAC2.13, R6.2
unnamed: L2.1, L3.1, L4.1, L5.1, R18.2

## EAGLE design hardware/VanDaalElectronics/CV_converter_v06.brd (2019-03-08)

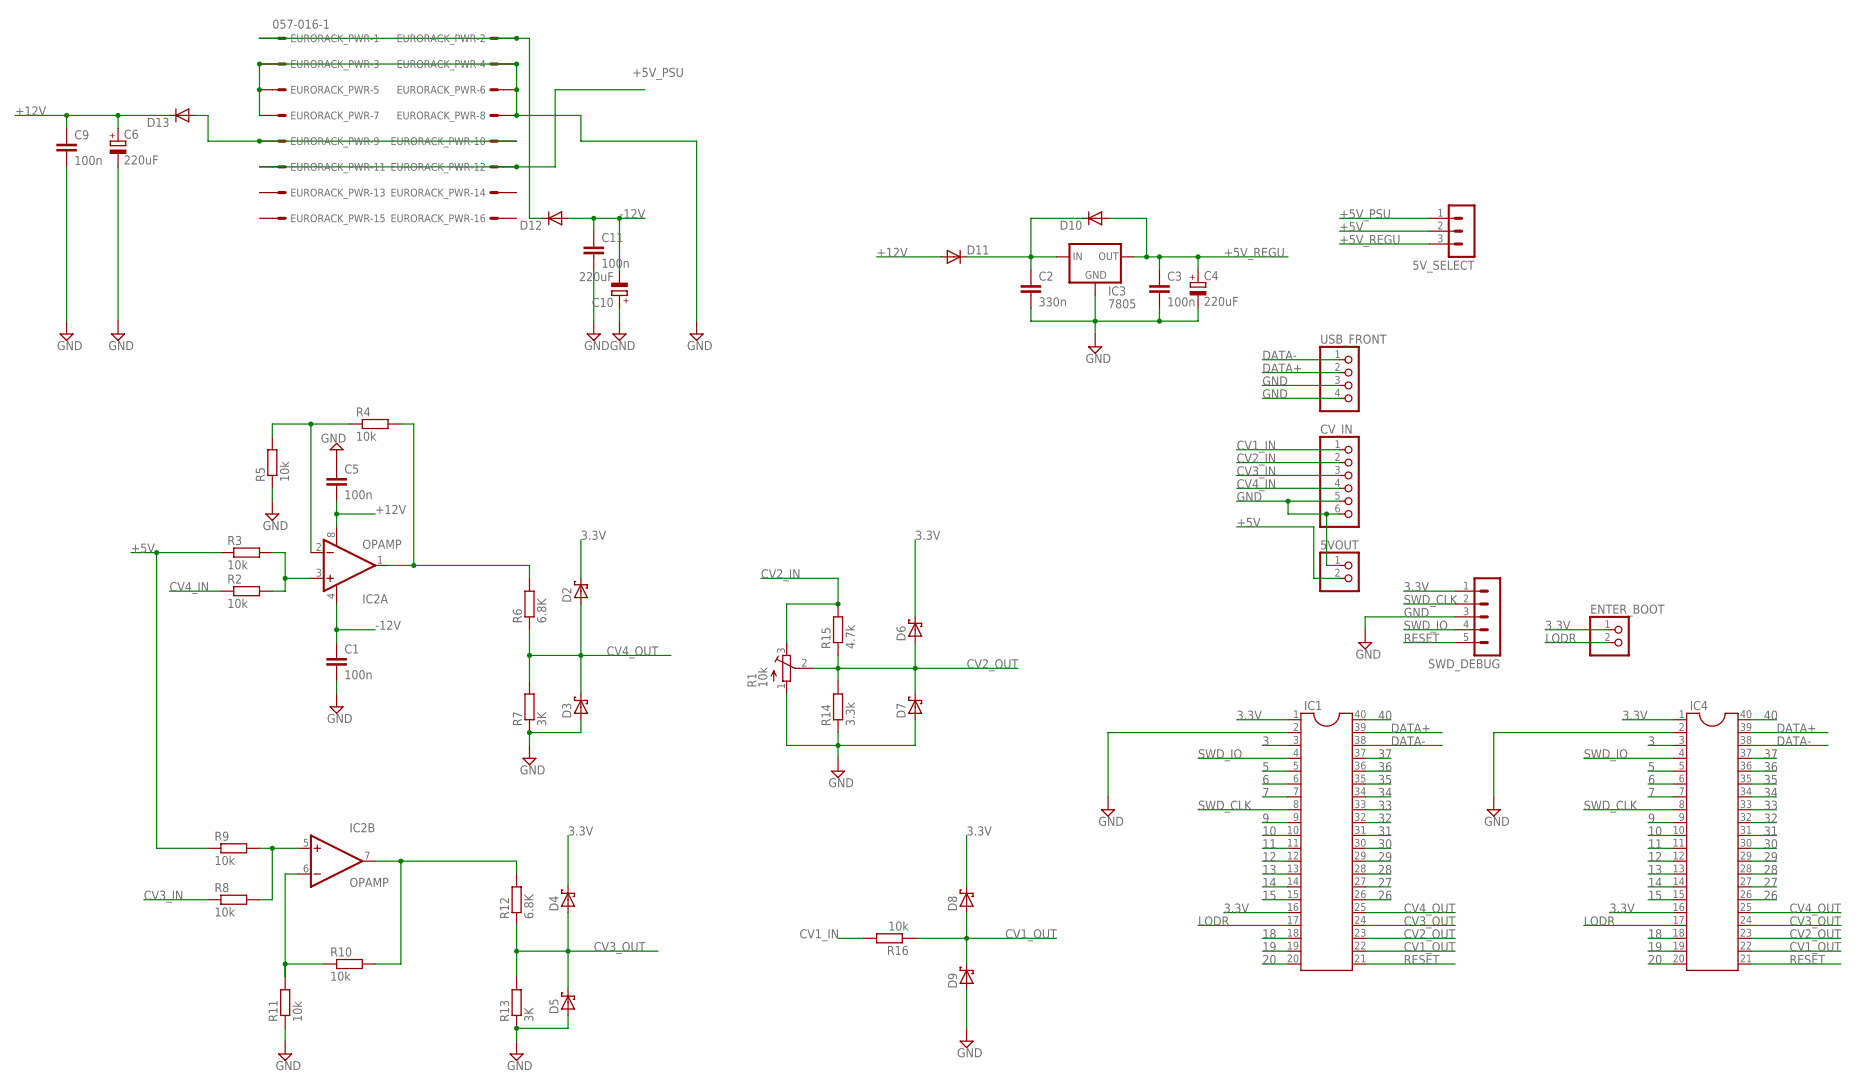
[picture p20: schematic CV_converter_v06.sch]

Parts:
5VOUT: PINHD-1X2; 1X02
5V_SELECT: MA03-1
C1, C3, C5, C9, C11: 100n; C025-025X050
C2: 330n; C025-025X050
C4, C6, C10: 220uF; E2,5-7
CV_IN: PINHD-1X6; 1X06
D2, D3, D4, D5, D6, D7, D8, D9: SCHOTTKY-DIODEDO35-7; DO35-7
D10, D11, D12, D13: DIODE-D-7.5; D-7.5
ENTER_BOOT: PINHD-1X2; 1X02
EURORACK_PWR: 057-016-1
IC1, IC4: DIL40
IC2: OPAMP; DIP08
IC3: 7805; TO-220-ALT
R1: 10k; RTRIM64W
R2, R3, R4, R5, R8, R9, R10, R11, R16: 10k; 0207/7
R6, R12: 6.8K; 0207/7
R7, R13: 3K; 0207/7
R14: 3.3k; 0207/7
R15: 4.7k; 0207/7
SWD_DEBUG: MA05-1
USB_FRONT: PINHD-1X4; 1X04

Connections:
3: IC1.3, IC4.3
3.3V: D2.C, D4.C, D6.C, D8.C, ENTER_BOOT.1, IC1.1, IC1.16, IC4.1, IC4.16, SWD_DEBUG.1
5: IC1.5, IC4.5
6: IC1.6, IC4.6
7: IC1.7, IC4.7
9: IC1.9, IC4.9
10: IC1.10, IC4.10
11: IC1.11, IC4.11
12: IC1.12, IC4.12
13: IC1.13, IC4.13
14: IC1.14, IC4.14
15: IC1.15, IC4.15
18: IC1.18, IC4.18
19: IC1.19, IC4.19
20: IC1.20, IC4.20
26: IC1.26, IC4.26
27: IC1.27, IC4.27
28: IC1.28, IC4.28
29: IC1.29, IC4.29
30: IC1.30, IC4.30
31: IC1.31, IC4.31
32: IC1.32, IC4.32
33: IC1.33, IC4.33
34: IC1.34, IC4.34
35: IC1.35, IC4.35
36: IC1.36, IC4.36
37: IC1.37, IC4.37
40: IC1.40, IC4.40
+5V: 5VOUT.2, 5V_SELECT.2, R3.1, R9.1
+5V_PSU: 5V_SELECT.1, EURORACK_PWR.11, EURORACK_PWR.12
+5V_REGU: 5V_SELECT.3, C3.1, C4.+, D10.A, IC3.OUT
+12V: C5.2, C6.+, C9.1, D11.A, D13.C, IC2.8 (V+)
-12V: C1.1, C10.-, C11.1, D12.A, IC2.4 (V-)
CV1_IN: CV_IN.1, R16.2
CV1_OUT: D8.A, D9.C, IC1.22, IC4.22, R16.1
CV2_IN: CV_IN.2, R1.3 (E), R15.2
CV2_OUT: D6.A, D7.C, IC1.23, IC4.23, R1.2 (S), R14.2, R15.1
CV3_IN: CV_IN.3, R8.1
CV3_OUT: D4.A, D5.C, IC1.24, IC4.24, R12.1, R13.2
CV4_IN: CV_IN.4, R2.1
CV4_OUT: D2.A, D3.C, IC1.25, IC4.25, R6.1, R7.2
DATA+: IC1.39, IC4.39, USB_FRONT.2
DATA-: IC1.38, IC4.38, USB_FRONT.1
GND: 5VOUT.1, C1.2, C2.2, C3.2, C4.-, C5.1, C6.-, C9.2, C10.+, C11.2, CV_IN.5, CV_IN.6, D3.A, D5.A, D7.A, D9.A, EURORACK_PWR.3, EURORACK_PWR.4, EURORACK_PWR.5, EURORACK_PWR.6, EURORACK_PWR.7, EURORACK_PWR.8, IC1.2, IC3.GND, IC4.2, R1.1 (A), R5.1, R7.1, R11.1, R13.1, R14.1, SWD_DEBUG.3, USB_FRONT.3, USB_FRONT.4
LODR: ENTER_BOOT.2, IC1.17, IC4.17
unnamed: IC2.1 (OUT), R4.2, R6.2
unnamed: IC2.3 (+IN), R2.2, R3.2
unnamed: C2.1, D10.C, D11.C, IC3.IN
unnamed: IC2.2 (-IN), R4.1, R5.2
unnamed: IC2.6 (-IN), R10.1, R11.2
unnamed: IC2.7 (OUT), R10.2, R12.2
unnamed: IC2.5 (+IN), R8.2, R9.2
unnamed: D12.C, EURORACK_PWR.1, EURORACK_PWR.2
unnamed: D13.A, EURORACK_PWR.9, EURORACK_PWR.10
RESET: IC1.21, IC4.21, SWD_DEBUG.5
SWD_CLK: IC1.8, IC4.8, SWD_DEBUG.2
SWD_IO: IC1.4, IC4.4, SWD_DEBUG.4

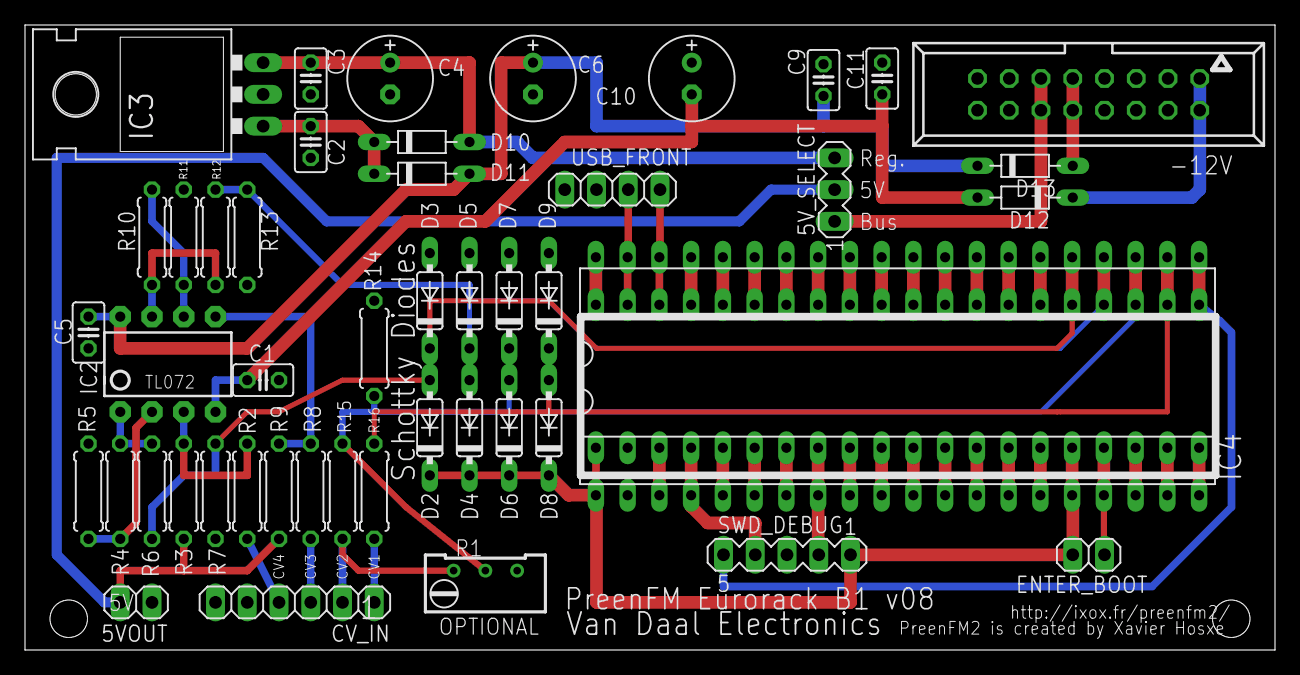
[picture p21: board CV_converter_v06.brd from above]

Board: 2 copper layers, 100.0 x 50.0 mm, 48 parts (0 on the bottom side), 57 nets.

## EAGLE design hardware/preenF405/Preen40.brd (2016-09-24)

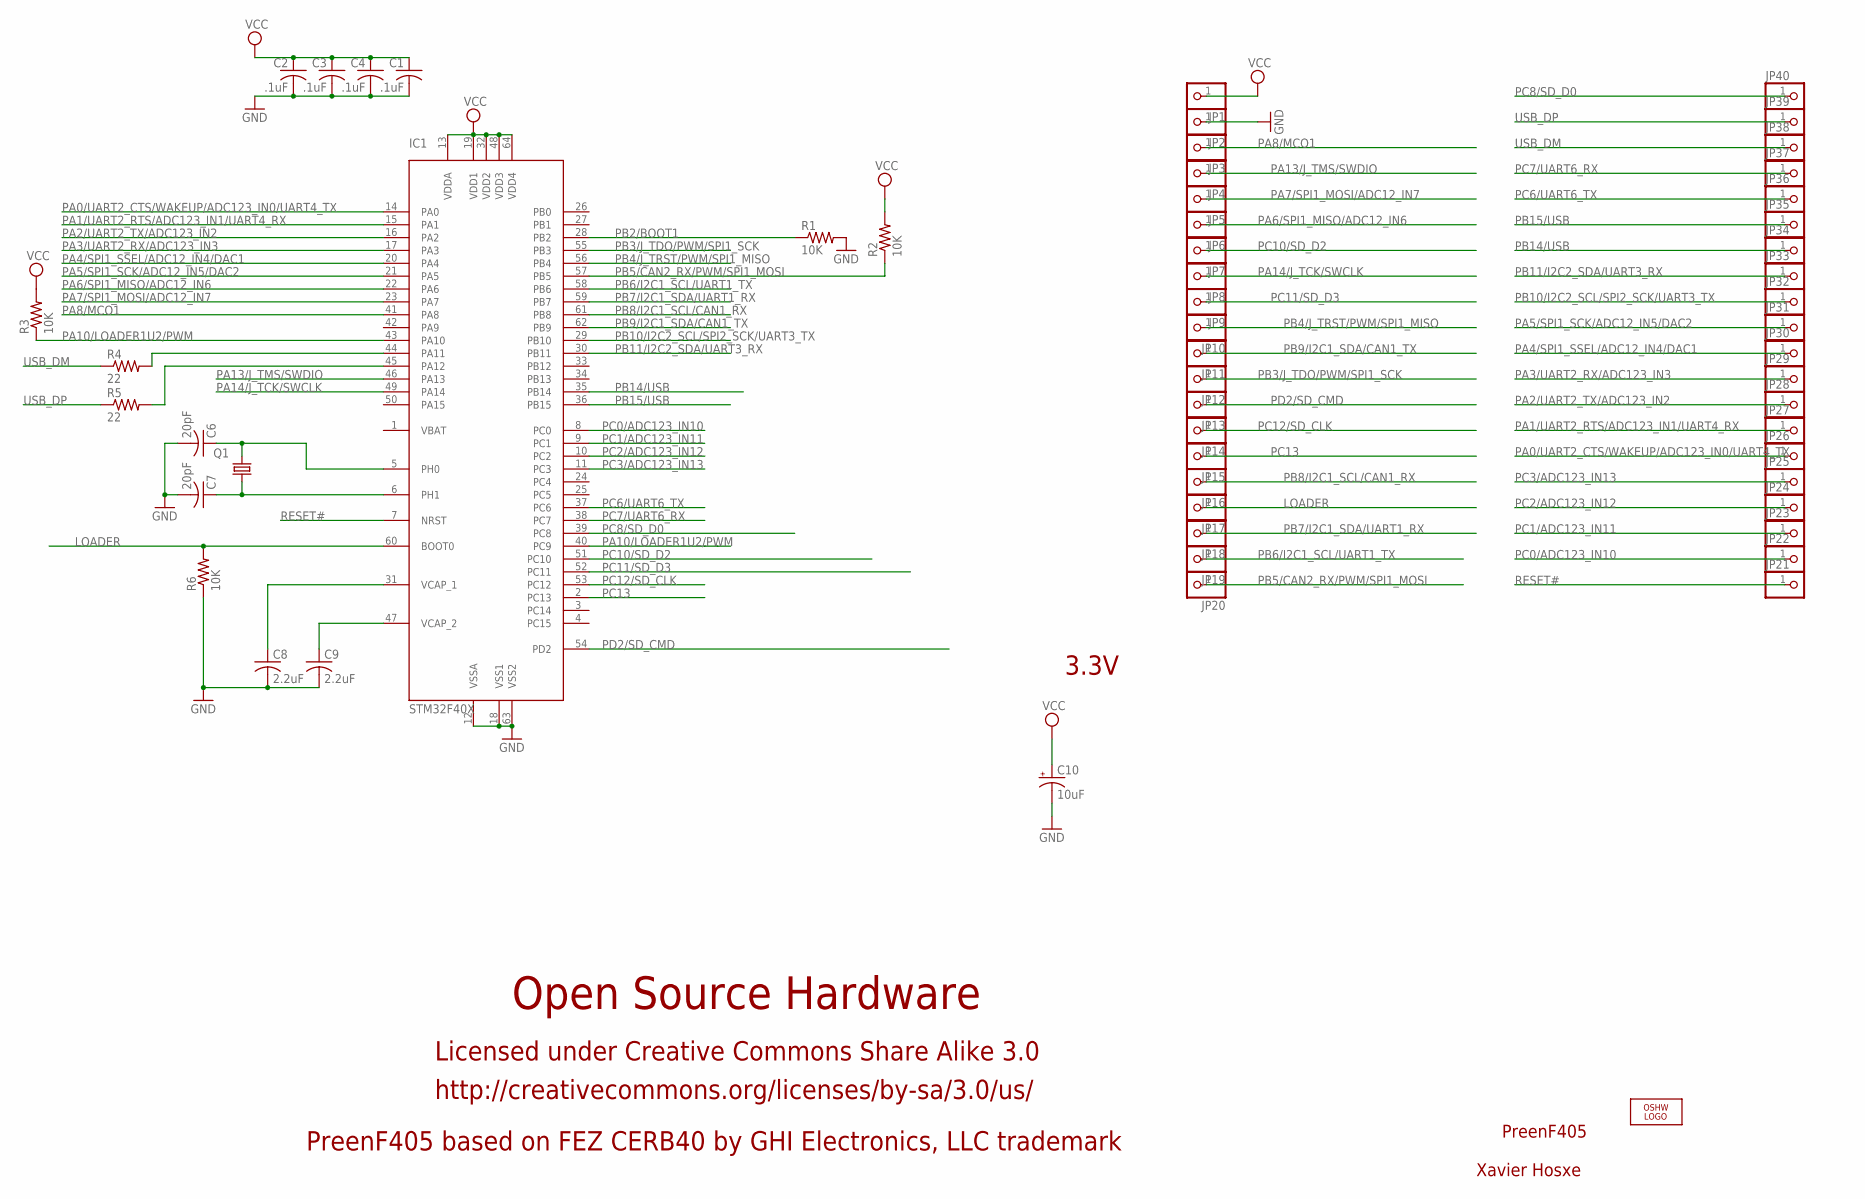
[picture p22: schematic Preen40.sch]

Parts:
C1, C2, C3, C4: .1uF; C0603K
C6, C7: 20pF; C0603K
C8, C9: 2.2uF; C0805K
C10: 10uF; CT3528
IC1: STM32F40X; LQFP64
JP1, JP2, JP3, JP4, JP5, JP6, JP7, JP8, JP9, JP10, JP11, JP12, JP13, JP14, JP15, JP16, JP17, JP18, JP19, JP20, JP21, JP22, JP23, JP24, JP25, JP26, JP27, JP28, JP29, JP30, JP31, JP32, JP33, JP34, JP35, JP36, JP37, JP38, JP39, JP40: PINHD-1X1; 1X01
LOGO1: LOGO-OSHW-FILLX0200-NT; OSHW_FILLX200_NOTEXT
Q1: 12Mhz; SM49@1
R1, R2, R3, R6: 10K; R0603
R4, R5: 22; R0603

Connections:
GND: C1.2, C2.2, C3.2, C4.2, C6.2, C7.2, C8.2, C9.2, C10.-, IC1.12 (VSSA), IC1.18 (VSS1), IC1.63 (VSS2), JP2.1, R1.2, R6.1
LOADER: IC1.60 (BOOT0), JP17.1, R6.2
unnamed: C9.1, IC1.47 (VCAP_2)
unnamed: C8.1, IC1.31 (VCAP_1)
unnamed: IC1.44 (PA11), R4.2
unnamed: IC1.45 (PA12), R5.2
PA0/UART2_CTS/WAKEUP/ADC123_IN0/UART4_TX: IC1.14 (PA0), JP26.1
PA1/UART2_RTS/ADC123_IN1/UART4_RX: IC1.15 (PA1), JP27.1
PA2/UART2_TX/ADC123_IN2: IC1.16 (PA2), JP28.1
PA3/UART2_RX/ADC123_IN3: IC1.17 (PA3), JP29.1
PA4/SPI1_SSEL/ADC12_IN4/DAC1: IC1.20 (PA4), JP30.1
PA5/SPI1_SCK/ADC12_IN5/DAC2: IC1.21 (PA5), JP31.1
PA6/SPI1_MISO/ADC12_IN6: IC1.22 (PA6), JP6.1
PA7/SPI1_MOSI/ADC12_IN7: IC1.23 (PA7), JP5.1
PA8/MCO1: IC1.41 (PA8), JP3.1
PA10/LOADER1U2/PWM: IC1.40 (PC9), IC1.43 (PA10), R3.1
PA13/J_TMS/SWDIO: IC1.46 (PA13), JP4.1
PA14/J_TCK/SWCLK: IC1.49 (PA14), JP8.1
PB2/BOOT1: IC1.28 (PB2), R1.1
PB3/J_TDO/PWM/SPI1_SCK: IC1.55 (PB3), JP12.1
PB4/J_TRST/PWM/SPI1_MISO: IC1.56 (PB4), JP10.1
PB5/CAN2_RX/PWM/SPI1_MOSI: IC1.57 (PB5), JP20.1, R2.1
PB6/I2C1_SCL/UART1_TX: IC1.58 (PB6), JP19.1
PB7/I2C1_SDA/UART1_RX: IC1.59 (PB7), JP18.1
PB8/I2C1_SCL/CAN1_RX: IC1.61 (PB8), JP16.1
PB9/I2C1_SDA/CAN1_TX: IC1.62 (PB9), JP11.1
PB10/I2C2_SCL/SPI2_SCK/UART3_TX: IC1.29 (PB10), JP32.1
PB11/I2C2_SDA/UART3_RX: IC1.30 (PB11), JP33.1
PB14/USB: IC1.35 (PB14), JP34.1
PB15/USB: IC1.36 (PB15), JP35.1
PC0/ADC123_IN10: IC1.8 (PC0), JP22.1
PC1/ADC123_IN11: IC1.9 (PC1), JP23.1
PC2/ADC123_IN12: IC1.10 (PC2), JP24.1
PC3/ADC123_IN13: IC1.11 (PC3), JP25.1
PC6/UART6_TX: IC1.37 (PC6), JP36.1
PC7/UART6_RX: IC1.38 (PC7), JP37.1
PC8/SD_D0: IC1.39 (PC8), JP40.1
PC10/SD_D2: IC1.51 (PC10), JP7.1
PC11/SD_D3: IC1.52 (PC11), JP9.1
PC12/SD_CLK: IC1.53 (PC12), JP14.1
PC13: IC1.2 (PC13), JP15.1
PD2/SD_CMD: IC1.54 (PD2), JP13.1
RESET#: IC1.7 (NRST), JP21.1
USB_DM: JP38.1, R4.1
USB_DP: JP39.1, R5.1
VCC: C1.1, C2.1, C3.1, C4.1, C10.+, IC1.13 (VDDA), IC1.19 (VDD1), IC1.32 (VDD2), IC1.48 (VDD3), IC1.64 (VDD4), JP1.1, R2.2, R3.2
XTAL3: C6.1, IC1.5 (PH0), Q1.2
XTAL4: C7.1, IC1.6 (PH1), Q1.1

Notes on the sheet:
PreenF405
Xavier Hosxe
Open Source Hardware
Licensed under Creative Commons Share Alike 3.0
PreenF405 based on FEZ CERB40 by GHI Electronics, LLC trademark
http://creativecommons.org/licenses/by-sa/3.0/us/
3.3V

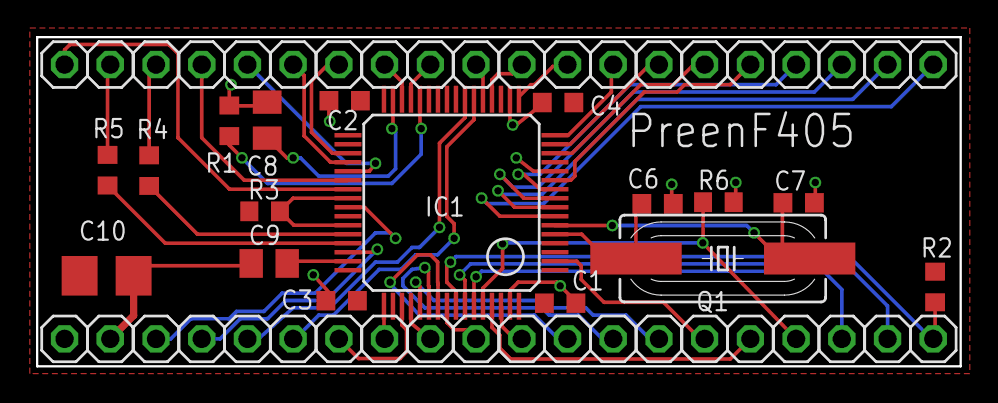
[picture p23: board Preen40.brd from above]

Board: 2 copper layers, 51.3 x 18.3 mm, 58 parts (1 on the bottom side), 48 nets.

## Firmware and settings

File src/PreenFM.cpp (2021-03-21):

/*
 * Copyright 2013
 *
 * Author: Xavier Hosxe (xavier . hosxe (at) gmail . com)
 *
 * This program is free software: you can redistribute it and/or modify
 * it under the terms of the GNU General Public License as published by
 * the Free Software Foundation, either version 3 of the License, or
 * (at your option) any later version.
 * This program is distributed in the hope that it will be useful,
 * but WITHOUT ANY WARRANTY; without even the implied warranty of
 * MERCHANTABILITY or FITNESS FOR A PARTICULAR PURPOSE.  See the
 * GNU General Public License for more details.
 * You should have received a copy of the GNU General Public License
 * along with this program.  If not, see <http://www.gnu.org/licenses/>.
 */

#include "PreenFM.h"
#include "Encoders.h"
#include "usbh_core.h"
#include "usbKey_usr.h"
#include "usbh_msc_core.h"
#include "usbd_core.h"
#include "usbd_usr.h"
#include "usbd_midi_desc.h"
#include "usbd_midi_core.h"
#include "FMDisplay.h"
#include "Synth.h"
#include "RingBuffer.h"
#include "MidiDecoder.h"
#include "Storage.h"
#include "Hexter.h"
#include "CVIn.h"

#include "ff.h"




SynthState         synthState __attribute__ ((section(".ccmnoload")));
Synth              synth __attribute__ ((section(".ccmnoload")));

// No need to put the following in the CCM memory
USB_OTG_CORE_HANDLE          usbOTGDevice;
LiquidCrystal      lcd ;
FMDisplay          fmDisplay ;
MidiDecoder        midiDecoder;
Encoders           encoders ;
Storage            usbKey ;
Hexter             hexter;
#ifdef CVIN
CVIn               cvin;
#endif
int spiState  __attribute__ ((section(".ccmnoload")));
float PREENFM_FREQUENCY __attribute__ ((section(".ccmnoload")));;
float PREENFM_FREQUENCY_INVERSED __attribute__ ((section(".ccmnoload")));;
float PREENFM_FREQUENCY_INVERSED_LFO __attribute__ ((section(".ccmnoload")));;

// Must be in memory accessible by DMA
int32_t dmaSampleBuffer[128];

uint16_t pinTest;

void setup() {
    // All bits for preemption
    NVIC_PriorityGroupConfig(NVIC_PriorityGroup_4);

    // What PCB version;
    synthState.setPcbVersion(getPcbVersion());

    if (synthState.getPcbVersion() == PCB_R5) {
        // 192000000 / 1142 / 4  :
        PREENFM_FREQUENCY = 42031.52f;
        synth.setDacNumberOfBits(18);
        pinTest = GPIO_Pin_4;
    } else {
        // See configurator
        // 43 500 000 / 1024 = 
        PREENFM_FREQUENCY = 42480.47f;
        synth.setDacNumberOfBits(24);
        pinTest = GPIO_Pin_14;
    }
    LEDFront_Config();
    LEDTest_Config(pinTest);

    

    PREENFM_FREQUENCY_INVERSED = 1.0f / PREENFM_FREQUENCY;
    PREENFM_FREQUENCY_INVERSED_LFO = PREENFM_FREQUENCY_INVERSED * 32.0f;

    lcd.begin(20, 4);

    LCD_InitChars(&lcd);

    for (int r=0; r<20; r++) {
    	lcd.setCursor(r,0);
    	lcd.print((char)0);
    	lcd.setCursor(r,1);
    	lcd.print((char)0);
    	lcd.setCursor(r,2);
    	lcd.print((char)0);
    	lcd.setCursor(r,3);
    	lcd.print((char)0);
    }

	USART_Config();
	RNG_Config();

	// Set flush to zero mode...
	// FPU will treat denormal value as 0

	//	You can avoid some of these support code requirements by:
	//enabling flush-to-zero mode, by setting the FZ bit, FPSCR[24], to 1
	//enabling default NaN mode, by setting the DN bit, FPSCR[25], to 1.
	//Some of the other support code requirements only occur when the appropriate feature is enabled. You enable:
	//Inexact exceptions by setting the IXE bit, FPSCR[12], to 1
	//Overflow exceptions by setting the OFE bit, FPSCR[10], to 1
	//Invalid Operation exceptions by setting the IOE bit, FPSCR[8], to 1.
	// Fast mode
	FPU->FPDSCR |= FPU_FPDSCR_FZ_Msk;
	FPU->FPDSCR |= FPU_FPDSCR_DN_Msk;
	FPU->FPDSCR &= ~(1UL << 12);
	FPU->FPDSCR &= ~(1UL << 10);
	FPU->FPDSCR &= ~(1UL << 8);
    // ---------------------------------------
    // Dependencies Injection

    // to SynthStateAware Class
    // MidiDecoder, Synth (Env,Osc, Lfo, Matrix, Voice ), FMDisplay, PresetUtil...

    synth.setSynthState(&synthState);
    fmDisplay.setSynthState(&synthState);
    midiDecoder.setSynthState(&synthState);
    midiDecoder.setVisualInfo(&fmDisplay);
#ifdef CVIN
    // synth needs visualInfo for CV gate
    synth.setVisualInfo(&fmDisplay);
    synth.setCVIn(&cvin);
#endif
    midiDecoder.setSynth(&synth);
    midiDecoder.setStorage(&usbKey);

    // ---------------------------------------
    // Register listener

    // synthstate is updated by encoder change
    encoders.insertListener(&synthState);

    // fmDisplay and synth needs to be aware of synthState changes
    // synth must be first one, can modify param new value
    /// order of param listener is important... synth must be called first so it's inserted last.
    synthState.insertParamListener(&fmDisplay);
    synthState.insertParamListener(&midiDecoder);
    synthState.insertParamListener(&synth);

    // Synth must be second to ba called first (to update global tuning before it's displayed)
    synthState.insertMenuListener(&fmDisplay);
    synthState.insertMenuListener(&synth);
    // Synth can check and modify param new value
    synthState.insertParamChecker(&synth);

    synthState.setStorage(&usbKey);
    synthState.setHexter(&hexter);


    usbKey.getPatchBank()->setSysexSender(&midiDecoder);
    // usbKey and hexter needs to know if arpeggiator must be loaded and saved
    usbKey.getPatchBank()->setArpeggiatorPartOfThePreset(&synthState.fullState.midiConfigValue[MIDICONFIG_ARPEGGIATOR_IN_PRESET]);
    hexter.setArpeggiatorPartOfThePreset(&synthState.fullState.midiConfigValue[MIDICONFIG_ARPEGGIATOR_IN_PRESET]);


    usbKey.init(synth.getTimbre(0)->getParamRaw(), synth.getTimbre(1)->getParamRaw(), synth.getTimbre(2)->getParamRaw(), synth.getTimbre(3)->getParamRaw());
    uint32_t waitCpt = 0;
    if (!usbKey.isKeyReady()) {
    	lcd.setCursor(0, 1);
    	lcd.print("   Insert Usb Key   ");
    	lcd.setCursor(0, 2);
    	lcd.print("                    ");
    }
    // Animation while waiting for Usb Key
    while (!usbKey.isKeyReady()) {
    	lcd.setCursor(0, 2);
    	lcd.print("                    ");
        int start = (waitCpt % 30) - 10;
        start = start > 0 ? start : 0;
        int end = (waitCpt % 30);
        end = end > 20 ? 20 : end;
    	lcd.setCursor(start, 2);
        for (uint8_t t = start; t < end; t++) {
            lcd.print('-');
        }
        usbKey.init(synth.getTimbre(0)->getParamRaw(), synth.getTimbre(1)->getParamRaw(), synth.getTimbre(2)->getParamRaw(), synth.getTimbre(3)->getParamRaw());
        waitCpt++;
    }

    usbKey.getConfigurationFile()->loadConfig(synthState.fullState.midiConfigValue);

    // initialize global tuning
    synth.updateGlobalTuningFromConfig();
#ifdef CVIN
    // Init formula with value
    cvin.updateFormula(synthState.fullState.midiConfigValue[MIDICONFIG_CVIN_A2], synthState.fullState.midiConfigValue[MIDICONFIG_CVIN_A6]);
#endif

    usbKey.getConfigurationFile()->loadScalaConfig(&synthState.fullState.scalaScaleConfig);

    // Load scala scales if enabled
    if (synthState.fullState.scalaScaleConfig.scalaEnabled) {
    	usbKey.getScalaFile()->loadScalaScale(&synthState.fullState.scalaScaleConfig);
    }


    if (synthState.getPcbVersion() == PCB_R5) {
        spiState = 0;
        MCP4922_SysTick_Config();
        MCP4922_Config();
        MCP4922_screenBoot(synth);
        fmDisplay.init(&lcd, &usbKey, 60 * PREENFM_FREQUENCY * .0001f);
    } else {
        // Same method but special case
        lcd.setRealTimeAction(true);
        CS4344_Config(dmaSampleBuffer);
        CS4344_screenBoot();
        fmDisplay.init(&lcd, &usbKey, 60.0f * 4.0f);
    }

    // FS = Full speed : midi
    // HS = high speed : USB Key
    // Init core FS as a midiStreaming device
    if (synthState.fullState.midiConfigValue[MIDICONFIG_USB] != USBMIDI_OFF) {
    	USBD_Init(&usbOTGDevice, USB_OTG_FS_CORE_ID, &usbdMidiDescriptor, &midiCallback, &midiStreamingUsrCallback);
    }


    // Load default combo if any
    usbKey.getComboBank()->loadDefaultCombo();
    // Load User waveforms if any
    usbKey.getUserWaveform()->loadUserWaveforms();
    // In any case init tables
    synthState.propagateAfterNewComboLoad();


    int bootOption = synthState.fullState.midiConfigValue[MIDICONFIG_BOOT_START];

    if (bootOption == 0) {
        fmDisplay.displayPreset();
        fmDisplay.setRefreshStatus(12);
    } else {
        // Menu
        synthState.buttonPressed(BUTTON_MENUSELECT);
        // Load
        synthState.buttonPressed(BUTTON_MENUSELECT);
        if (bootOption == 1) {
        	// Bank
            synthState.buttonPressed(BUTTON_MENUSELECT);
        } else if (bootOption == 2) {
        	// Combo
            synthState.encoderTurned(0, 1);
            synthState.buttonPressed(BUTTON_MENUSELECT);
        } else if (bootOption == 3) {
        	// DX7
            synthState.encoderTurned(0, 1);
            synthState.encoderTurned(0, 1);
            synthState.buttonPressed(BUTTON_MENUSELECT);
        }
        // First preset...
        synthState.buttonPressed(BUTTON_MENUSELECT);
    }


    // Init ADC
#ifdef CVIN
    ADC_Config(cvin.getADCBufferAdress());
#endif
}

unsigned int ledTimer = 0;
bool ledState = false;
unsigned int encoderTimer = 0;
unsigned int tempoTimer = 0;
unsigned int ADCTimer = 0;


#ifdef DEBUG_CPU_USAGE
unsigned int tDebug;
#endif

 
void strobeLed(uint32_t sync1, uint32_t sync2) {
    if (ledState) {
        if ((preenTimer - ledTimer) > sync1) {
            GPIO_ResetBits(GPIOC, pinTest);
            ledTimer = preenTimer;
            ledState = false;
        }
    } else {
        if ((preenTimer - ledTimer) > sync2) {
            GPIO_SetBits(GPIOC, pinTest);
            ledTimer = preenTimer;
            ledState = true;
        }
    }
}


void MCP4922_loop(void) {
    fillSoundBuffer();

    unsigned int newPreenTimer = preenTimer;

	// Comment following line for debug....
	lcd.setRealTimeAction(false);

	// newByte can display visual info
    while (usartBufferIn.getCount() > 0) {
        fillSoundBuffer();
		midiDecoder.newByte(usartBufferIn.remove());
	}

	if ((newPreenTimer - encoderTimer) > 80) {
        fillSoundBuffer();
        encoders.checkStatus(synthState.fullState.midiConfigValue[MIDICONFIG_ENCODER]);
        encoderTimer = newPreenTimer;
    } else if (fmDisplay.needRefresh()) {
        fillSoundBuffer();
        fmDisplay.refreshAllScreenByStep();
    }

    if ((newPreenTimer - tempoTimer) > 10000) {
         fillSoundBuffer();
         synthState.tempoClick();
         fmDisplay.tempoClick();


#ifdef CVIN
        if (synthState.fullState.currentMenuItem->menuState == MENU_CONFIG_SETTINGS &&
                (synthState.fullState.menuSelect == MIDICONFIG_CVIN_A2 || synthState.fullState.menuSelect == MIDICONFIG_CVIN_A6)) {
            if (cvin.getGate() > (synthState.fullState.midiConfigValue[MIDICONFIG_CV_GATE] * 9 + 62)) {
                lcd.setCursor(1, 3);
                lcd.print("(");
                lcd.print(cvin.getMidiNote());
                lcd.print(") ");
                lcd.setCursor(9, 3);
                lcd.print(": ");
                lcd.print(cvin.getMidiNote1024());
                lcd.print(" ");
            }
        }
#endif


         tempoTimer = newPreenTimer;
     }

    lcd.setRealTimeAction(true);
    while (lcd.hasActions()) {
        if (usartBufferIn.getCount() > 20) {
            // We don't want real time update of parameters
            lcd.setRealTimeAction(false);
            while (usartBufferIn.getCount() > 0) {
                fillSoundBuffer();
                midiDecoder.newByte(usartBufferIn.remove());
            }
            lcd.setRealTimeAction(true);
        }
        LCDAction action = lcd.nextAction();
        lcd.realTimeAction(&action, fillSoundBuffer);
    }

    strobeLed(4203, (42031 * 2- 4203));

#ifdef DEBUG_CPU_USAGE
    if ((preenTimer - tDebug) >= 500) {
        tDebug = preenTimer;
        lcd.setCursor(12, 1);
        lcd.print('>');
        lcd.printWithOneDecimal(synth.getCpuUsage());
        lcd.print('%');
        lcd.print('<');

        lcd.setCursor(14, 2);
        lcd.print('>');
        lcd.print((int)synth.getPlayingNotes());

        lcd.print('<');
    }
#endif


}


void CS4344_loop(void) {

	// Comment following line for debug....
	lcd.setRealTimeAction(false);


    // New midi data ?
    // Move to DMA1_Stream5_IRQHandler ? 
    // Would be better i think
    while (usartBufferIn.getCount() > 0) {
        midiDecoder.newByte(usartBufferIn.remove());
    }

    if ((preenTimer - encoderTimer) >= 2) {
        // Surface control ?
        encoders.checkStatus(synthState.fullState.midiConfigValue[MIDICONFIG_ENCODER]);
        encoderTimer = preenTimer;
    } 
    
    if (fmDisplay.needRefresh()) {
        // Display to refresh ?
        fmDisplay.refreshAllScreenByStep();
    }

    // 1312 per seconds
    if ((preenTimer - tempoTimer) > 328) {
        // display to update
        synthState.tempoClick();
        fmDisplay.tempoClick();

        tempoTimer = preenTimer;
    }

#ifdef DEBUG_CPU_USAGE
    if ((preenTimer - tDebug) >= 600) {
        tDebug = preenTimer;
        lcd.setCursor(12, 1);
        lcd.print('>');
        lcd.printWithOneDecimal(synth.getCpuUsage());
        lcd.print('%');
        lcd.print('<');

        lcd.setCursor(15, 2);
        lcd.print('>');
        lcd.print(synth.getPlayingNotes());

        lcd.print('<');
    }
#endif

    lcd.setRealTimeAction(true);
    while (lcd.hasActions()) {
        if (usartBufferIn.getCount() > 20) {
            // We don't want real time update of parameters
            lcd.setRealTimeAction(false);
            while (usartBufferIn.getCount() > 0) {
                midiDecoder.newByte(usartBufferIn.remove());
            }
            lcd.setRealTimeAction(true);
        }
        LCDAction action = lcd.nextAction();
        lcd.realTimeAction(&action, fillSoundBuffer);
    }

    strobeLed(131, (1312 * 2 - 131));
}

int main(void) {
    setup();
    if (synthState.getPcbVersion() == PCB_R5) {
        while (1) {
            MCP4922_loop();
        }
    } else {
        while (1) {
            CS4344_loop();
        }
    }
}

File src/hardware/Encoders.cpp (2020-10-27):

/*
 * Copyright 2013 Xavier Hosxe
 *
 * Author: Xavier Hosxe (xavier <dot> hosxe (at) g m a i l <dot> com)
 *
 * This program is free software: you can redistribute it and/or modify
 * it under the terms of the GNU General Public License as published by
 * the Free Software Foundation, either version 3 of the License, or
 * (at your option) any later version.
 * This program is distributed in the hope that it will be useful,
 * but WITHOUT ANY WARRANTY; without even the implied warranty of
 * MERCHANTABILITY or FITNESS FOR A PARTICULAR PURPOSE.  See the
 * GNU General Public License for more details.
 * You should have received a copy of the GNU General Public License
 * along with this program.  If not, see <http://www.gnu.org/licenses/>.
 */


#include "Encoders.h"
#include "stm32f4xx_gpio.h"
#include "stm32f4xx_rcc.h"


#include "LiquidCrystal.h"
extern LiquidCrystal lcd;


Encoders::Encoders() {
	// PreenFM PCB R4
    char encoderPins[] = { 12, 14, 1, 13, 2, 8, 3, 7};
    char buttonPins[] = { 9, 16, 10, 15, 11, 5, 4, 6};

    // GPIOG Periph clock enable
	RCC_AHB1PeriphClockCmd(RCC_AHB1Periph_GPIOA, ENABLE);

	/* Configure PB5 in output mode */
	GPIO_InitTypeDef GPIO_InitStructure;
	GPIO_InitStructure.GPIO_Pin = HC165_CLOCK | HC165_LOAD;
	GPIO_InitStructure.GPIO_Mode = GPIO_Mode_OUT;
	GPIO_InitStructure.GPIO_OType = GPIO_OType_PP;
	GPIO_InitStructure.GPIO_Speed = GPIO_Speed_100MHz;
	GPIO_InitStructure.GPIO_PuPd = GPIO_PuPd_NOPULL;
	GPIO_Init(GPIOA, &GPIO_InitStructure);

	GPIO_InitTypeDef GPIO_InitStructure2;

    GPIO_InitStructure2.GPIO_PuPd = GPIO_PuPd_NOPULL;
    GPIO_InitStructure2.GPIO_Pin = HC165_DATA;
	GPIO_InitStructure2.GPIO_Mode = GPIO_Mode_IN;
	GPIO_Init(GPIOA, &GPIO_InitStructure2);


	GPIO_ResetBits(GPIOA, HC165_CLOCK);
	GPIO_ResetBits(GPIOA, HC165_LOAD);

	/*
			0: 0000 = 00
			1: 0001 = 00
			2: 0010 = 00
			3: 0011 = 00
			4: 0100 = 02
			5: 0101 = 00
			6: 0110 = 00
			7: 0111 = 01 // 1
			8: 1000 = 00
			9: 1001 = 00
			A: 1010 = 00
			B: 1011 = 02 // 2
			C: 1100 = 00
			D: 1101 = 00
			E: 1110 = 00
			F: 1111 = 00
	*/
	// PIC11 ... N24
    int actionToCopy[2][16] = {     /* N12 */{ 0, 0, 0, 0, 2, 0, 0, 1, 1, 0, 0, 2, 0, 0, 0, 0},
                                    /* N24 */ { 0, 0, 0, 0, 0, 0, 0, 1, 0, 0, 0, 2, 0, 0, 0, 0}
    };

    for (int i=0; i<2; i++) {
        for (int j=0; j<16; j++) {
            action[i][j] = actionToCopy[i][j];
        }
    }

    firstListener= 0;


	for (int k=0; k<NUMBER_OF_ENCODERS; k++) {
		encoderBit1[k] = 1 << (encoderPins[k*2] -1);
		encoderBit2[k] = 1 << (encoderPins[k*2 + 1] -1);
		lastMove[k] = LAST_MOVE_NONE;
		tickSpeed[k] = 1;
	}

	for (int k=0; k<NUMBER_OF_BUTTONS; k++) {
		buttonBit[k] = 1 << (buttonPins[k] -1);
		buttonPreviousState[k] = false;
		// > 30
		buttonTimer[k] = 31;
		buttonUsedFromSomethingElse[k] = false;
	}

	encoderTimer = 0;
	firstButtonDown = -1;

}

Encoders::~Encoders() {
}


int Encoders::getRegisterBits() {
	// Copy the values in the HC165 registers
	GPIO_ResetBits(GPIOA, HC165_LOAD);
	GPIO_SetBits(GPIOA, HC165_LOAD);

	// Analyse the new value
	int registerBits = 0;
	for(int i=0; i<16; i++) {
		GPIO_ResetBits(GPIOA, HC165_CLOCK);
		registerBits |= (GPIO_ReadInputDataBit(GPIOA, HC165_DATA) << i) ;
		GPIO_SetBits(GPIOA, HC165_CLOCK);
	}
	return registerBits;
}

void Encoders::checkSimpleStatus() {
	int registerBits = getRegisterBits();


	for (int k=0; k<NUMBER_OF_BUTTONS; k++) {
		// button is pressed ?
		bool b1 = ((registerBits & buttonBit[k]) == 0);
		// button is pressed
		if (b1) {
			if (buttonTimer[k] > 30) {
				buttonPressed(k);
			}
			buttonTimer[k]=0;
		}
		buttonTimer[k]++;
	}
}

void Encoders::checkStatus(int encoderType) {
	int registerBits = getRegisterBits();

	// target the right action row.
	// encoderType : First bit for type, second bit for inversed
	int *actionEnc = action[encoderType & 0x1];
	int inversedEnc = (encoderType & 0x2) == 0 ? 1 : -1;

	for (int k=0; k<NUMBER_OF_ENCODERS; k++) {
		bool b1 = ((registerBits & encoderBit1[k]) == 0);
		bool b2 = ((registerBits & encoderBit2[k]) == 0);

		encoderState[k] <<= 2;
		encoderState[k] &= 0xf;
		if (b1) {
			encoderState[k] |= 1;
		}
		if (b2) {
			encoderState[k] |= 2;
		}

		if (actionEnc[encoderState[k]] == 1 && lastMove[k]!=LAST_MOVE_DEC) {
			encoderTurned(k, tickSpeed[k] * inversedEnc);
			tickSpeed[k] += 3;
			lastMove[k] = LAST_MOVE_INC;
			timerAction[k] = 60;
		} else if (actionEnc[encoderState[k]] == 2 && lastMove[k]!=LAST_MOVE_INC) {
			encoderTurned(k, -tickSpeed[k] * inversedEnc);
			tickSpeed[k] += 3;
			lastMove[k] = LAST_MOVE_DEC;
			timerAction[k] = 60;
		} else {
			if (timerAction[k] > 1) {
				timerAction[k] --;
			} else if (timerAction[k] == 1) {
				timerAction[k] --;
				lastMove[k] = LAST_MOVE_NONE;
			}
			if (tickSpeed[k] > 1 && ((encoderTimer & 0x3) == 0)) {
				tickSpeed[k] = tickSpeed[k] - 1;
			}
		}
		if (tickSpeed[k] > 10) {
			tickSpeed[k] = 10;
		}
	}

	for (int k=0; k<NUMBER_OF_BUTTONS; k++) {
		bool b1 = ((registerBits & buttonBit[k]) == 0);

		// button is pressed
		if (b1) {
			buttonTimer[k]++;
			// just pressed ?
			if (!buttonPreviousState[k]) {
				if (firstButtonDown == -1) {
					firstButtonDown = k;
					buttonUsedFromSomethingElse[k] = false;
				} else {
					twoButtonsPressed(firstButtonDown, k);
					buttonUsedFromSomethingElse[firstButtonDown] = true;
					buttonUsedFromSomethingElse[k] = true;
				}
			}
		} else {
			// Just unpressed ?
			if (buttonPreviousState[k]) {
				if (firstButtonDown == k) {
					firstButtonDown = -1;
				}
				if (buttonPreviousState[k] && !buttonUsedFromSomethingElse[k]) {
					// Just released
					if (buttonTimer[k] > 15) {
						buttonPressed(k);
					}
				}
				buttonTimer[k]=0;
			}
		}

		buttonPreviousState[k] = b1;
	}
	encoderTimer++;
}

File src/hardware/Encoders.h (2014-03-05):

/*
 * Copyright 2013 Xavier Hosxe
 *
 * Author: Xavier Hosxe (xavier . hosxe (at) gmail . com)
 *
 * This program is free software: you can redistribute it and/or modify
 * it under the terms of the GNU General Public License as published by
 * the Free Software Foundation, either version 3 of the License, or
 * (at your option) any later version.
 * This program is distributed in the hope that it will be useful,
 * but WITHOUT ANY WARRANTY; without even the implied warranty of
 * MERCHANTABILITY or FITNESS FOR A PARTICULAR PURPOSE.  See the
 * GNU General Public License for more details.
 * You should have received a copy of the GNU General Public License
 * along with this program.  If not, see <http://www.gnu.org/licenses/>.
 */

#ifndef ENCODERS_H_
#define ENCODERS_H_

#include "RingBuffer.h"
#include "EncodersListener.h"

#define HC165_CLOCK GPIO_Pin_8
#define HC165_DATA  GPIO_Pin_7
#define HC165_LOAD  GPIO_Pin_6

#define NUMBER_OF_ENCODERS 4
#define NUMBER_OF_BUTTONS 8

enum LastEncoderMove {
	LAST_MOVE_NONE = 0,
	LAST_MOVE_INC,
	LAST_MOVE_DEC
};


struct EncoderStatus {
	char value;
	bool b1;
};

class Encoders {
public:
	Encoders();
	~Encoders();
	void checkStatus(int encoderType);
	void checkSimpleStatus();
	int getRegisterBits();

	void insertListener(EncodersListener *listener) {
		if (firstListener!=0) {
			listener->nextListener = firstListener;
		}
		firstListener = listener;
	}

	void encoderTurned(int encoder, int ticks) {
		if (firstButtonDown == -1) {
			for (EncodersListener* listener = firstListener; listener !=0; listener = listener->nextListener) {
				listener->encoderTurned(encoder, ticks);
			}
		} else {
			for (EncodersListener* listener = firstListener; listener !=0; listener = listener->nextListener) {
				listener->encoderTurnedWhileButtonPressed(encoder, ticks, firstButtonDown);
			}
			buttonUsedFromSomethingElse[firstButtonDown] = true;
		}
	}

	void encoderTurnedWileButtonDown(int encoder, int ticks) {
		for (EncodersListener* listener = firstListener; listener !=0; listener = listener->nextListener) {
			listener->encoderTurned(encoder, ticks);
		}
	}


	void buttonPressed(int button) {
		for (EncodersListener* listener = firstListener; listener !=0; listener = listener->nextListener) {
			listener->buttonPressed(button);
		}
	}

	void twoButtonsPressed(int button1, int button2) {
		for (EncodersListener* listener = firstListener; listener !=0; listener = listener->nextListener) {
			listener->twoButtonsPressed(button1, button2);
		}
	}

private:
	int action[2][16];
	int encoderBit1[NUMBER_OF_ENCODERS];
	int encoderBit2[NUMBER_OF_ENCODERS];
	int encoderState[NUMBER_OF_ENCODERS];
	int timerAction[NUMBER_OF_ENCODERS];

	LastEncoderMove lastMove[NUMBER_OF_ENCODERS];
    int tickSpeed[NUMBER_OF_ENCODERS];

	int buttonBit[NUMBER_OF_BUTTONS];
	int buttonTimer[NUMBER_OF_BUTTONS];
	bool buttonUsedFromSomethingElse[NUMBER_OF_BUTTONS];
	bool buttonPreviousState[NUMBER_OF_BUTTONS];
	int firstButtonDown;

	int encoderTimer;

	EncodersListener* firstListener;
};

#endif /* ENCODERS_H_ */

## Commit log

2013-04-25 Fix voices assignation when loading combo
    [MidiDecoder.cpp, PreenFM.cpp, Synth.cpp]
2013-05-28 Fix MidiClock bug with LfoOsc
    [FMDisplay.cpp]
2013-06-15 Option added for 2 encoder drivers for PEC11*N12 and PEC11*N24.
2013-06-19 Fix CC and NRPN...
    [MidiDecoder.cpp]
2013-06-22 Fix bugs : nb of voice ==0 & gliding
    [Synth.cpp]
2013-06-25 Clean up + small fix.
    [FMDisplay.cpp, PreenFM.cpp]
2013-06-30 Sysex in/out of current patch.
2013-07-11 Fix number of voice after loading a new patch.
    [Synth.cpp]
2013-07-15 Fixes + Enveloppe release level
    [FMDisplay.cpp, MidiDecoder.cpp]
2013-07-17 DX7 adjustement wirh Rom1B.syx + bug fix (new param load... lfo reconfigured)
    [FMDisplay.cpp, MidiDecoder.cpp, Synth.cpp]
2013-07-30 Sysex bank now saved correctly in named USB bank.
    [BootLoader.cpp, FMDisplay.cpp, MidiDecoder.cpp]
2013-08-10 Fixed Control change transmission
    [MidiDecoder.cpp]
2013-08-10 Bootloader can now jump to STM32F4 system boot loader
2013-08-10 Bootloader properly versioned + USB update fixed
    [BootLoader.cpp]
2013-08-10 Remove HQ (interpolation but slower) sample
2013-08-11 Usb love... freeze fixed + menu to disable Usb midi (Off - in - in/out)
    [MidiDecoder.cpp, PreenFM.cpp]
2013-08-11 LCD realtime false + save name bug fixed.
    [PreenFM.cpp]
2013-08-31 Fix swap emnu : op option and encoder type.
2013-11-25 Add twoButtonsPressed() in EncodersListener. Use it to test note.
2013-12-06 Fix some display problem + use of led
    [BootLoader.cpp, FMDisplay.cpp, PreenFM.cpp]
2013-12-15 Running status correctly reset on System Common Messages.
    [MidiDecoder.cpp]
2013-12-28 Refactoring + bug fix (USB / Midi) + boot animation&sound + hold pedal CC
    [BootLoader.cpp, Encoders.cpp, Encoders.h]
2013-12-29 Fix bug / optimization : Midi, usb, sysex
    [BootLoader.cpp, FMDisplay.cpp, MidiDecoder.cpp]
2014-01-02 Optimization (likely / unlikely / satuation inline assembly / -Ofast)
2014-01-03 Fix holdPedal when voice=1 and gliding
    [Synth.cpp]
2014-01-05 Add print(unsigned int)
2014-01-05 Fix HardFault when displaying some parameter of DX7 imported patch.
    [FMDisplay.cpp]
2014-01-16 Default Velocity Higher - Structure for Params in Memory - IM per note
2014-01-16 Fixed velocity in ALGO17 & 18
2014-01-26 1.B2 : fix + new mixer + CC as source + OLED screen saver + New LFO
    [FMDisplay.cpp]
2014-02-01 1.B3 : Algo bug fix (mix/cache/DC fitler) from kuzma's feedback + Settings in text file
    [FMDisplay.cpp, PreenFM.cpp]
2014-02-06 Fixed voice allocation bugs. getFreeVoice + Timbre::preenNewNote.
    [Synth.cpp]
2014-02-08 First 1.B5 commit : DX7 velocity IM improved + program change CC fixed
    [MidiDecoder.cpp]
2014-03-05 1.B6 : fixed glide display bug + USB aftertouch Iternal refactoring
    [Encoders.cpp, Encoders.h, FMDisplay.cpp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]
2014-03-13 1.B8 : arpeggiator as played + note on alocation reworked
    [Synth.cpp]
2014-03-16 Better push timer for bootloader
2014-03-23 1.B10: sysex, fix missing notes, negative perf values, usbMidi fixes, clean
    [FMDisplay.cpp, MidiDecoder.cpp, PreenFM.cpp]
2014-03-26 1.B11 : LFO.Ksyn => 16.0s + several small fixes in the LF area
    [FMDisplay.cpp]
2014-04-02 Add fancy pattern edit modes using encoders 2+3
2014-04-03 Makefile 1.B12 + KSyn display fixe bug (4.00 correctly displayed)
    [FMDisplay.cpp]
2014-04-09 Ensure valid menu row when switching instruments, return to last state
2014-04-10 Fix boundary case of navigation, move #define to header
2014-04-12 Fix regression in navigation and use correct button for env rows
2014-07-15 1.03 : nrpn preset flush are now done correctly on the right midi channel
    [MidiDecoder.cpp]
2015-08-09 1.07b1 Scala
    [ConfigurationFile.h]
2016-09-14 FIX : IM* target matrix can correctly decrease velocity IM
2016-09-24 PreenF405 eagle Schema added
    [Preen40.brd, Preen40.sch]
2016-10-11 Revert "Strict NRPN option added : use 7bits (CC6 only) when sufficient"
    This reverts commit 4ffa40c3e819c186cf1b49844e744488c2d04e78.
    [MidiDecoder.cpp]
2016-11-16 New svg case files
2016-11-17 hardwae/case : hardware list added
2017-05-29 PCB r5d files added
    [PreenFM.brd, PreenFM.kicad_pcb, PreenFM.sch]
2017-07-12 Add preenF405 detailed BOM
2017-10-22 2.08b2 lfo rate up to 99.9hz +fixes
    [FMDisplay.cpp]
2017-11-05 Fix NRPN step sequencer
    [MidiDecoder.cpp, Synth.cpp]
2017-11-07 CC cannot make filter Freq and Res > 1.00
2018-10-13 Fix Op 1&4 default combo release time
    [PreenFM.cpp]
2018-10-27 Preset modified by midi : optimization + CRASH fix when number of voices too high
    [Synth.cpp]
2018-10-27 Display refresh optimisation on midi update + fix some preset display that show up when it should not
    [FMDisplay.cpp, MidiDecoder.cpp]
2019-01-27 Inversed encoders supported
2019-03-08 Van Daal Electronics CB converter PCB added
    [CV_converter_v06.brd, CV_converter_v06.sch, PreenFM.brd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]
2019-05-04 Schematics in pdf
2019-05-30 New midi channel for current instrument + new CC(119) to modify current instrument
2019-05-30 New case svg files added
2019-05-30 Eurorack + gate + v/oct + tunable
    [ConfigurationFile.h]
2019-05-30 better calibration display
2019-05-30 Fix bug with Gate On when switch on
    [CVIn.cpp, PreenFM.cpp]
2019-08-08 new filter flavour + tilt filter
2019-08-10 some filter tweak+code cleaning
2019-08-10 added allpass, saturator & sigmoid filters
2019-08-11 allpass filter used for a stereo enhancer filter
2019-08-15 missing matrix filter controls added
2019-08-15 lowered resonance in tilt filter
2019-08-16 renamed allpass filter->stereo
2019-08-17 wrap filter added
2019-08-24 added FILTER_LPXOR1&2 + reworked xor fx + modified fx levels to match each others
2019-08-25 added lphp filter
2019-08-27 added notch & lp3 filters
2019-08-29 added bell filter
2019-09-02 added lowshelf & highshelf filters
2019-09-10 sig, fold, wrap filter change
2019-09-13 FILTER_LPXOR rework
2019-09-21 svf filters cleanup, added LPSin, HPSin, BPSin
2019-10-06 textures slight mod + rollback some ap filters
2019-10-10 AP4D : Diffusion allpass filter + ap fx tweak
2019-10-23 formantic filter + ap polish
2019-10-26 formant filter wip
2019-11-01 tanh optimization, formant filter tweak
2019-11-05 added ladder filter
2019-11-30 added h3o+ filter
2019-12-14 Put back original README + filters part added
2019-12-14 velocity fix + code cleaning
2019-12-14 h3o+ : remove accent circuit
2019-12-14 accent is back on teebee filter
2020-01-09 2.11b1 : filter order changed
2020-08-21 CC10 & CC7 / 3 bug fixed / 192Mhz is the new default
    [MidiDecoder.cpp, PreenFM.cpp]
2020-10-25 Fix first bit problem with i2s (sound saturation)
    [PreenFM.cpp, Synth.cpp]
2020-10-27 Bootloader modificaiton (USB access still does not work)
    [BootLoader.cpp]
2020-11-06 3D printed case added
    [bottom.stl, front15mm.stl, pfm2case.f3d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]
2021-02-16 Bug fix : load preset freeze + button shortcut
2021-03-06 Fix chars all over the screen when receiving patch from the Editor
    [PreenFM.cpp]
2021-03-28 Top Surface PCB v1.0
    [pfm2_topSurface-B_Cu.gbr, pfm2_topSurface-B_Mask.gbr, pfm2_topSurface-B_Paste.gbr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]
2021-04-13 Fix non-pfm2 sysex problem
    [pfm2_topSurface.kicad_pcb]
2021-04-17 Case_PCB all files
    [pfm2-Case.stl, pfm2-Rear.stl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]
2021-08-22 2.21b : Fix Attk midi CC
    [MidiDecoder.cpp]

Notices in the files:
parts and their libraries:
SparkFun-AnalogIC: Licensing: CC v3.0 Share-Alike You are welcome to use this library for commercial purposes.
